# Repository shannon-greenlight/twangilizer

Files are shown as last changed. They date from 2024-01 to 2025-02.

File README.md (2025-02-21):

# Twangilizer - 4 Harmonic Tracking Oscillator with 4 VCAs
Twangilizer is a 20HP Eurorack module designed and made by Greenface Labs.
Used in conjunction with a VCO and a multiple-output CV generating module such as the Bonkulator, Twangilizer is a great way to set the amplitude envelopes of a tone and 4 of its harmonics. 
The harmonics are selectable from 1f, 2f, 3f, 4f, 5f, 6f, 7f and 8f. They are available as square waves at the output jacks 1-4.
The harmonics are also used to generate 10-step sine-wave approximations. The amplitudes of these waves are set by the CV inputs and then added to form the analog signal output.

Twangilizer features one signal input, an analog signal output, 4 digital harmonic outputs, 4 CV bias level adjustment pots, and four CV inputs to the VCAs.
It also features harmonic selection controls: Four 8 position rotary switches to select the harmonic from the above list. And there is a toggle switch per channel that selects divide by one, or divide by two.

The signal input level must be greater than .1Vp-p for the phase-locked loop circuits to be able to lock on.
The output signal ranges from 0 to 10Vp-p. The CV inputs range is 0 - 10V.

These repos contain the materials needed to construct the Twangilizer main board and the front panel. The files are for KiCAD 6.0. 
Go to the Greenlight Kicad repo to get the needed libraries. The gerber files work with JLCPC and will most likely work with other board manufacturers.

When using the JLCPCB assembly service, the BOM is split into 3 parts.
- bom/lcsc/main_bom.xlsx : The parts to be assembled by JLCPCB
- bom/digi-key/main_split.xlsx : The remaining parts to be assembled by user
- bom/other/other_bom.xlsx : The parts that must be bought from sources other than JLCPCB and Digi-Key

Also, when an assembly service is used, a component position file is required. This file's path is: fab/main_cpl.xlsx

notes: 	The cpl files are auto-generated from the .pos files produced by KiCAD. The bom files are generated by generate_boms.bat. You will need to refresh the data and save the file when changes to 
the schematic that affect the BOM or changes to the board layout occur. 
If they exist, the extra parts and additional data fields that appear on the schematic help to produce the different BOM files. 
They must be maintained for these BOMs to come out right.

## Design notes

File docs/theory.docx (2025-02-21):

# Twangilizer Theory of Operation

## Description:

The Twangilizer is a Eurorack module that fits in a 3U x 20HP format. It is an “additive synthesis” module that generates four sine waves that are harmonically related to a given input signal.

Using the 8-position rotary switches, the user can select from 8 harmonics (1f – 8f). The resulting signals can be used as-is or can be halved in frequency by the toggle switches. This gives the user many interesting options when creating a sound.

The levels of the resulting harmonics can be adjusted using the front panel potentiometers and/or via the CV inputs. An indicator LED displays the level of the adjustment.

## Inputs:

1. Clock input. Accepts signals > .1V peak-to-peak. 20 – 20KHz. An LED indicates CLK present.
2. CV1 – CV4. Control the level of the harmonics sent to Analog Out. 0-8V range.

## Outputs:

1. Analog Out. Sum of all four harmonics.
2. Sync Outputs 1-4. Digital outputs of the four harmonics. For syncing other modules.

## Several circuit blocks are used to implement the Twangilizer:

1. Power Supply
2. Clock capture
3. Harmonic generators
4. Waveform generators
5. Tracking Filters
6. Signal reconstruction
7. VCAs
8. Digital Outputs
9. Analog Output

## Power Supply

The power connector is “Either Way” but should be tested with a diode tester to make sure the diodes have been installed correctly. BAT54 SCHOTTKY diodes are used. They are rated at 200mA. The +12V rail pulls 100mA max and the -12V rail much less than that. Assuming a total current of 150mA through the package with a worst-case 1V drop, we get a power dissipation of only 150mW. According to the datasheet, derating occurs at 50C, so overheating under normal operating conditions shouldn’t be an issue.

The resulting voltages after the diode drops are typically +11.5V and -11.6V given +/-12V inputs. This leaves enough headroom for the op amps that may need to deal with +/-10V signals.

The +9V rail is derived from the +12V supply. The -9V rail is derived from +9V.

The harmonic and waveform generators use +9V and -9V. These functions require good regulation to achieve a stable waveform. The LM317 used for the +9V requires a certain amount of headroom (see further discussion at end of this document), or else +10V would have been chosen, as the PLLs work best with higher supply voltages. However, 9V is good enough. The -9V rail requires less than 200uA, so an op amp regulator is ideal here.

The symmetry of the waveform depends on the absolute value of the -9V rail being close to the +9V rail. For this reason, .1% resistors were chosen.

Also, the bias point for the VCO pickoff circuits is set by the -9V. This is a sensitive parameter, so it needs to be accurate. A 500ohm trimpot adjusts the +9V rail. With components at their nominal values, an adjustment range of 8.61V – 9.62V is achieved. The nominal adjustment range is skewed so that the worst-case range is adequate and as symmetrical about the 9V value as possible. The results of this are:

1. Set RV1 to 200ohms for 9.01V when all components are nominal.
2. Worst case lower value is 8.76V
3. Worst case upper value is 9.21V

Refer to lm317.xlsx for the calculations used in this discussion.

### Tests

1. D1 – D4 correctly installed
2. +12 > 11.4
3. -12 > -11.5
4. Adjust +9V between 8.95V and 9.05V
5. -9V within .5% of +9V magnitude.

## Clock Capture

The clock capture circuit supplies the signal to the harmonic generators. It is spec'd for a signal greater than .1Vpp in amplitude and works in the range of 20Hz – 20KHz.

Refer to spice\CLK Pickoff.asc for the following discussion.

The input signal is AC coupled and then low-pass filtered. The signal is then given a gain of 46.2 which forms a band pass filter whose characteristics are shown in the graph below.

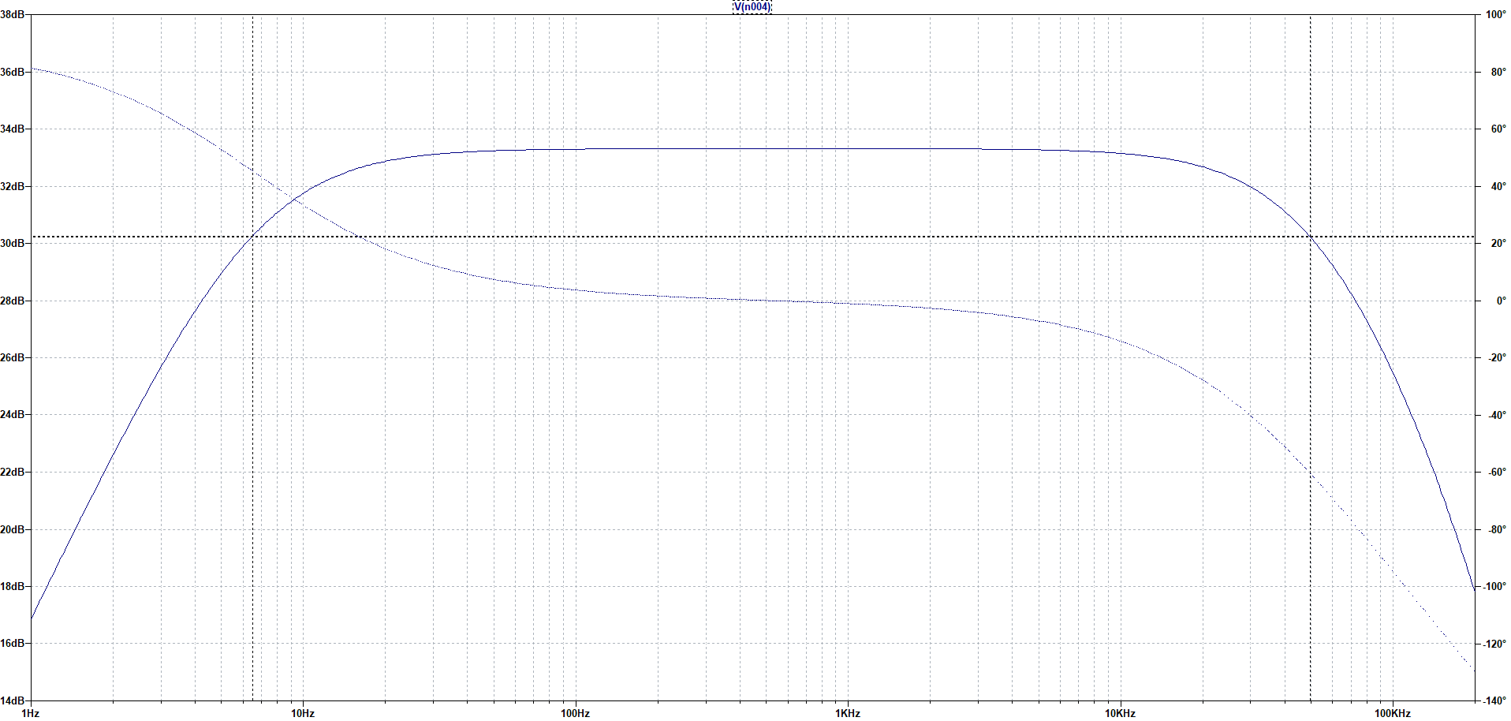
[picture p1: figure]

The -3dB points are approximately 6.6Hz and 50KHz.

This signal is passed to a comparator which has a hysteresis of .94V. The comparator’s trip point is skewed slightly positive from 0V. This prevents the Clock Present LED from lighting when no signal is present due to offset voltage errors inherent in the op amp.

Finally, the signal is sent to a transistor circuit that level-shifts it to a 9V digital wave that is compatible with the harmonic and waveform generators.

Another transistor circuit drives a “Clock Present” indicator LED.

All tests are performed with a 30mVpp sine wave input.

### Tests

1. CLK waveform good at 20Hz
2. CLK waveform good at 20KHz
3. No CLK at 10Hz
4. No CLK at 30KHz
5. CLK present indicator OFF when no clock is present
6. CLK present indicator ON when clock is present

## Harmonic Generators

The harmonics are generated using phase locked loops with down counters whose outputs are routed to the reset input via the 8-position rotary switches. This arrangement creates a frequency multiplier of 1f – 8f depending on the position of the switch. The signal can be further modified by the toggle switches that follow. These are either connected to the signal or to a flip-flop that divides the frequency in half. When the frequency divider position is chosen, you get the resulting frequencies: 1/2f, 1f, 3/2f, 2f, 5/2f, 3f, 7/2f, 4f.

There is a foible in the circuit when in 1f mode. A race condition exists that sometimes results in the output signal oscillating at around 110KHz. This is fixed by the slight delay added to the 1f position via a 1K resistor and 10pF capacitor.

No testing is needed here unless subsequent stages fail.

If testing is required, the signal can be measured at the center pin of the divide-by-two toggle switches. A 1KHz clock signal is adequate for the following tests.

### Tests

1. CLK signal correct for all 8 rotary switch settings
2. CLK signal correct for both toggle switch settings

## Waveform Generators

The outputs of the Harmonic Generators are fed to the Waveform Generators which create the sinewave approximations. These 10-step waveforms are created by CD4046/CD4017 combinations that are similar to the Harmonic Generators.

But instead of selectable ratios, these circuits are set to multiply by 10. Each output of the CD4017 is sent through a resistor to a summing amplifier. The gain of this amp is set to produce a signal compatible with the next stage. The resulting signal from the Waveform Generators is -3dBm @600 or .547VRMS.

The peak value of the current going into the summing junction is set at 15uA. So, the current will vary from -15uA to +15uA to create a bipolar signal at the output. But, since only positive currents are available from the +9V powered CD4017, a -45uA offset is added using -9V through a 200K resistor. This offset must be accounted for in the resistor calculation.

In the equation below, we see 15uA as the peak current times the sine of the sum of 0-.9 and a phase offset of .125 (to improve wave shape) times 2π. The 45uA offset is added to this value.

Note that the sine calculation is in Radians.

Refer to wavegen.xlsx for the following discussion.

Here is the Excel calculation for the ideal resistor values: (see below table)

G =0.000015*SIN((F?+.125)*6.2832)+0.000045 defines current through the resistor

H =9/G? defines ideal resistor value

F | G | H
0 | 5.56066E-05 | 161851.2
0.1 | 5.98153E-05 | 150463.1
0.2 | 5.83651E-05 | 154201.8
0.3 | 5.18098E-05 | 173712.4
0.4 | 4.26534E-05 | 211003.3
0.5 | 3.43933E-05 | 261678.9
0.6 | 3.01846E-05 | 298164.8
0.7 | 3.1635E-05 | 284495.2
0.8 | 3.81903E-05 | 235661.8
0.9 | 4.73467E-05 | 190087

Real resistor values have been substituted in the following table and graph:

I | J | K
162000 | 1.06E-05 | -0.55206
1.50E+05 | 0.000015 | -0.7845
1.54E+05 | 1.34E-05 | -0.70299
1.74E+05 | 6.72E-06 | -0.35167
2.10E+05 | -2.1E-06 | 0.112071
2.61E+05 | -1.1E-05 | 0.550052
3.00E+05 | -1.5E-05 | 0.7845
2.87E+05 | -1.4E-05 | 0.71343
2.37E+05 | -7E-06 | 0.367424
1.91E+05 | 2.12E-06 | -0.1109
162000 | 1.06E-05 | -0.55206
1.50E+05 | 0.000015 | -0.7845
1.54E+05 | 1.34E-05 | -0.70299
1.74E+05 | 6.72E-06 | -0.35167
2.10E+05 | -2.1E-06 | 0.112071
2.61E+05 | -1.1E-05 | 0.550052
3.00E+05 | -1.5E-05 | 0.7845
2.87E+05 | -1.4E-05 | 0.71343
2.37E+05 | -7E-06 | 0.367424
1.91E+05 | 2.12E-06 | -0.1109

J =9/I?-0.000045

K =-52300*J?

Equation K shows the 52.3K resistor that sets the gain of the summing amplifier.

Dividing the peak value of .7845V by the square root of two results in .555VRMS. The 100pF cap in the feedback filters the high frequency components (-3dB @30KHz) of the signal and reduces the amplitude to near the desired .547VRMS.

The Tracking Filters in the next section take their input from the VCO pins of the CD4046s. The response of the PLLs must be adjusted to work with the Tracking Filters. Set the input clock frequency to 1KHz and adjust the pot (RV6-RV9) until a voltage of -4.2V is measured at the VCO pickoff test points. (TP8 – TP11).

### Tests (measured at TP4 – TP7)

1. OSC waveform good at 20Hz
2. OSC waveform good at 20KHz

## Tracking Filters

The job of the tracking filters is to produce sine waves from the approximate waveforms formed by the Waveform Generators described above. The tracking filters use the VCO in of the PLL chips to sense the frequency and set the corner frequency of the filters as required.

The CD4046 phase locked loop IC has a capture range defined by the RC combination of the cap that appears between pins 6 and 7 and the resistor chain that is connected to pin 11. With a resistor that has a nominal value of 35K (10K plus half the 50K of the trimpot) and a capacitor of 2.2nF, you get a center frequency around 20KHz when the circuit is configured as a 10f multiplier. See fig. 5 in the data sheet.

Increasing RC reduces the upper capture point and increases the slope of the pickoff curve.

The graph below shows the pickoff level vs. the input clock frequency.

The filters use a signal that ranges from -10VDC to +10VDC to set their cutoff frequency. The table below shows the Ideal curve which was empirically derived. It also shows the results measured from a v0.0 Twangilizer VCO Pickoff. Finally, it shows the computed curve.

Refer to VCO Pickoff Meas.xlsx for the following data.

Freq | Ideal | VCO Pickoff | Computed
5000 | 10.2 | 7.68 | 17.64
4000 | 10 | 6.18 | 11.265
3000 | 5 | 4.77 | 5.2725
2000 | 0 | 3.47 | -0.2525
1000 | -5 | 2.27 | -5.3525
500 | -7.62 | 1.71 | -7.7325
250 | -9.06 | 1.43 | -8.9225
100 | -9.88 | 1.25 | -9.6875
50 | -10.17 | 1.16 | -10.07
20 | -10.17 | 1.07 | -10.4525

Planned =(Pickoff*4.25)-15 The resulting curve for the tracking filters looks something like the following measured trace:

The signal from the VCO is not a pure DC signal. It contains pulses that continually correct the output frequency. These pulses must be filtered lest they affect the output signal. A single stage filter with a cutoff frequency of 6.8KHz accomplishes this task. The 499K pickoff resistor and a 47pF cap is used.

A spreadsheet that was used to select resistor values is found here: VCO Pickoff Plan.xlsx

### Tests

Measure at TP12 – TP19

1. 1f waveform good at 20Hz CLK
2. 1f waveform good at 5KHz CLK
3. Measure 50Hz at 100Hz CLK for 1f/2
4. 2f waveform good at 20Hz CLK
5. 2f waveform good at 5KHz CLK
6. 3f waveform good at 20Hz CLK
7. 3f waveform good at 6.67KHz CLK
8. 4f waveform good at 5KHz CLK
9. 5f waveform good at 20Hz CLK
10. 5f waveform good at 4KHz CLK
11. 6f waveform good at 20Hz CLK
12. 6f waveform good at 3.33KHz CLK
13. 7f waveform good at 20Hz CLK
14. 7f waveform good at 2.86KHz CLK
15. 8f waveform good at 20Hz CLK
16. 8f waveform good at 2.5KHz CLK

## VCAs

Now that the frequency of the harmonic has been set and the tracking filter has turned the output of the waveform generator into a sine wave, the level must be set. This is accomplished using a voltage-controlled amplifier.

See spice\VCA.asc

There are two control inputs to the VCA, one from the CV input jack which is protected in the usual way with a 510ohm resistor and a BAT54S; and one set by the CV bias potentiometer. The 510ohms is small enough in resistance to be insignificant to the 120K input.

Since the bias pot uses +9V as its reference, the voltage divider is adjusted to match the range of the CV input by the 150K resistor. In either case, this sets the full-scale voltage value at the non-inverting input of the op amp to be 5V. This implies 5V at the inverting input which sets an LED current of 250uA. (5V / 20K)

When the CV bias pot is used in conjunction with the CV input, the bias sets a current level that is increased by the CV input only when it exceeds the voltage level of the CV bias. A transfer function curve of CV input vs LED current best illustrates this. The bias pot is set to 50% in this example.

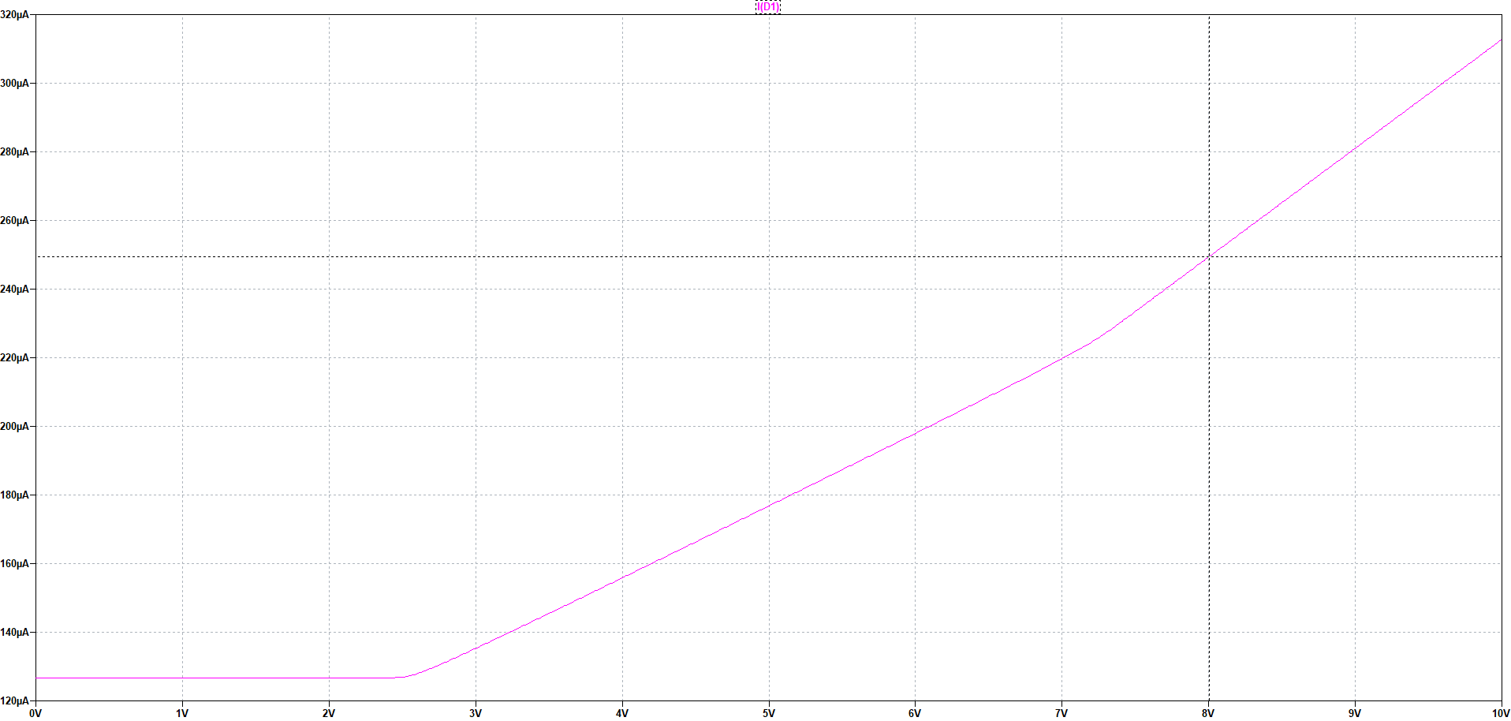
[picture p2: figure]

Here we see the LED current at 125uA until the CV input is greater than 2.5V. This is because diode D4 does not conduct until the CV input exceeds 2.5V. The current then increases with CV until the maximum of 250uA is reached.

With the CV bias set to 100%, the base current will be 250uA. In this case the CV input will increase the current to a maximum of 330uA with the increase starting when the CV input exceeds 5V.

In the above example, the slight upturn when CV input is greater than 7V occurs when D3 becomes reverse biased.

BAT54 Schottky diodes are placed in series with the sense resistors to minimize interaction due to resistive loading. According to the manual, the maximum leakage current of a BAT54 at 25V is 2uA. The worst-case condition in this circuit is 10V. The manual indicates the typical leakage at 10V is .1uA. The manual also states that, for the current this circuit will experience, the diodes will have a forward voltage drop of only .12V. Conveniently, these are the values that are used by the Spice simulator.

The VCA circuit uses a vactrol as the controlled element. The NSL-32SR3 has a nominal resistance of 600 ohms with an LED current of 250uA. The output of the Signal Reconstruction element is approximately 3.5Vp-p. This must be raised to the specified output level of 10Vp-p. This implies a gain of 2.86 which is realized by the 1K in series with the 2K trimpot at 50% divided by the 600 ohms of the full-scale resistance of the vactrol.

This also gives a transfer function of roughly 1V at CVin equals 1Vpp at Analog Out.

An indicator LED is put in series with the vactrol LED as an indication of the control voltage level.

### Tests

Measure at Analog Output, CLK input 1000Hz.

1. 0V CV, bias adjustment off. Measure < .1VRMS.
2. 1V CV, bias adjustment off. Measure 1Vpp +/-2%
3. 8V CV, bias adjustment off. Measure 8Vpp +/-2%
4. 0V CV, bias adjustment 50%. Measure 5Vpp +/-5%
5. 0V CV, bias adjustment 100%. Measure 10Vpp +/-5%

## Digital Outputs

The digital outputs are +5V square waves generated from the outputs of the Harmonic Generators. These outputs are 9V square waves and must be level-shifted to the required 5V. The 9V signal is reduced to 4.9V by a resistive divider formed by 10K and 12K resistors. This is fed into the non-inverting input of an op amp.

A 20pF capacitor from the non-inverting input to ground limits the slew rate of the input signal which minimizes ringing at the output.

The output is protected by the usual 510 ohm/BAT54S combination.

## Analog Output

The analog output is the sum of the four VCA outputs. It is followed by a 4th order Butterworth 5KHz low pass filter. The output is protected by the usual 510ohm/BAT54 circuit.

The curve of the filter is modeled in the file: spice\final_output.asc

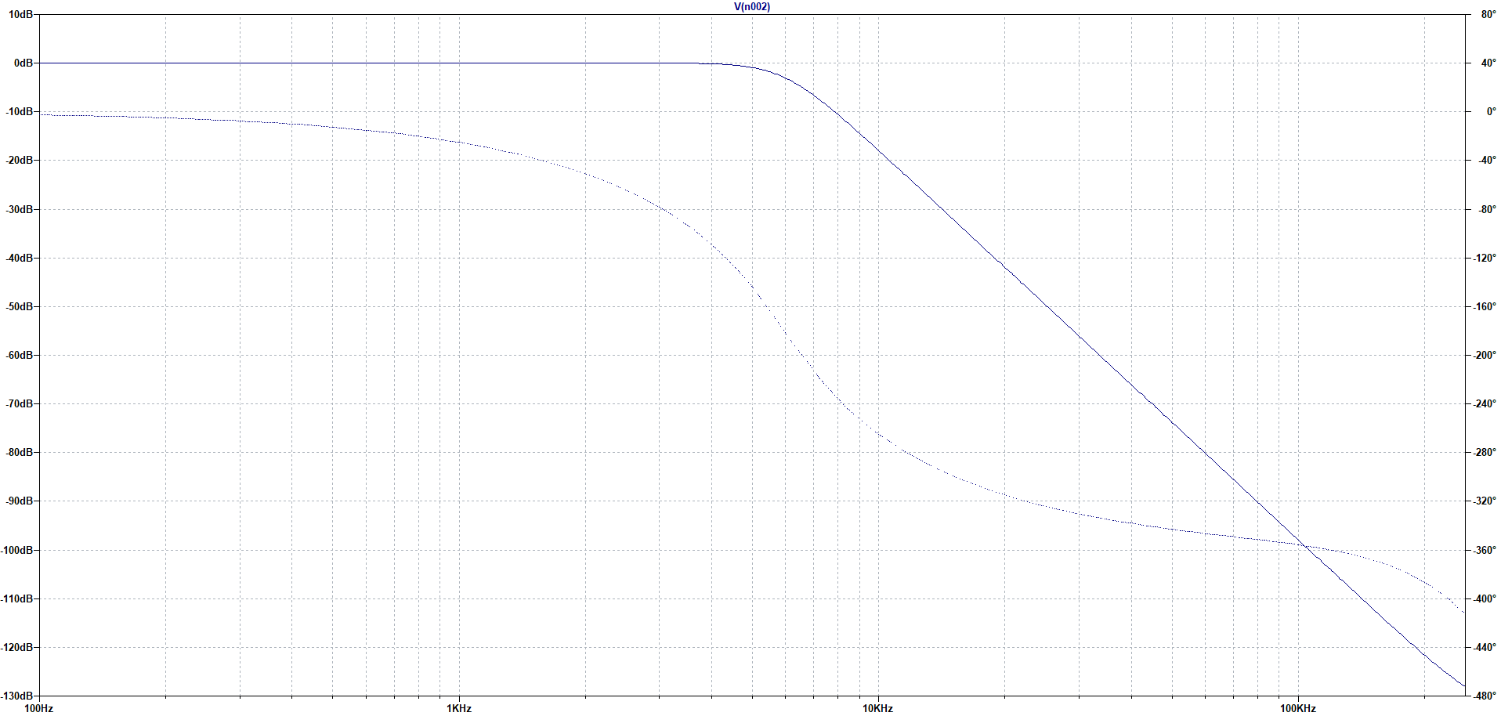
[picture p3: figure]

## Clip Detector

The clip detector circuit is placed at the analog output of the Twangilizer and is set to detect clipping when the signal exceeds 9Vpk. The circuit is unique for a clip detector in that it flashes an LED at a rate proportional to the amount of clipping. This is opposed to increasing the intensity of the LED as the signal level increases.

This behavior is desirable because a flashing LED is more noticeable than a steady-state LED of varying brightness.

The circuit consists of a non-precision full-wave rectifier followed by a comparator .

The circuit is pictured below. The SPICE simulation is below that.

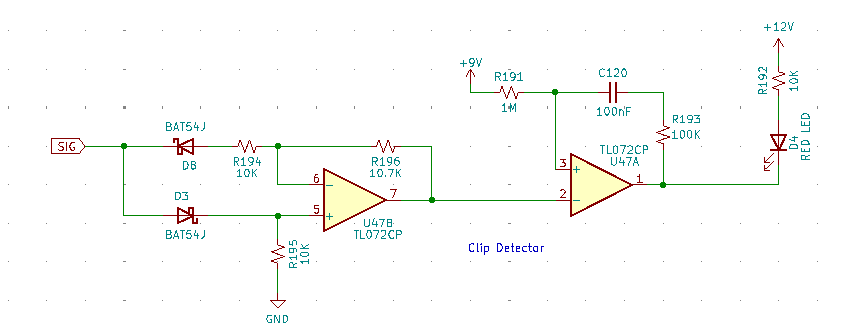
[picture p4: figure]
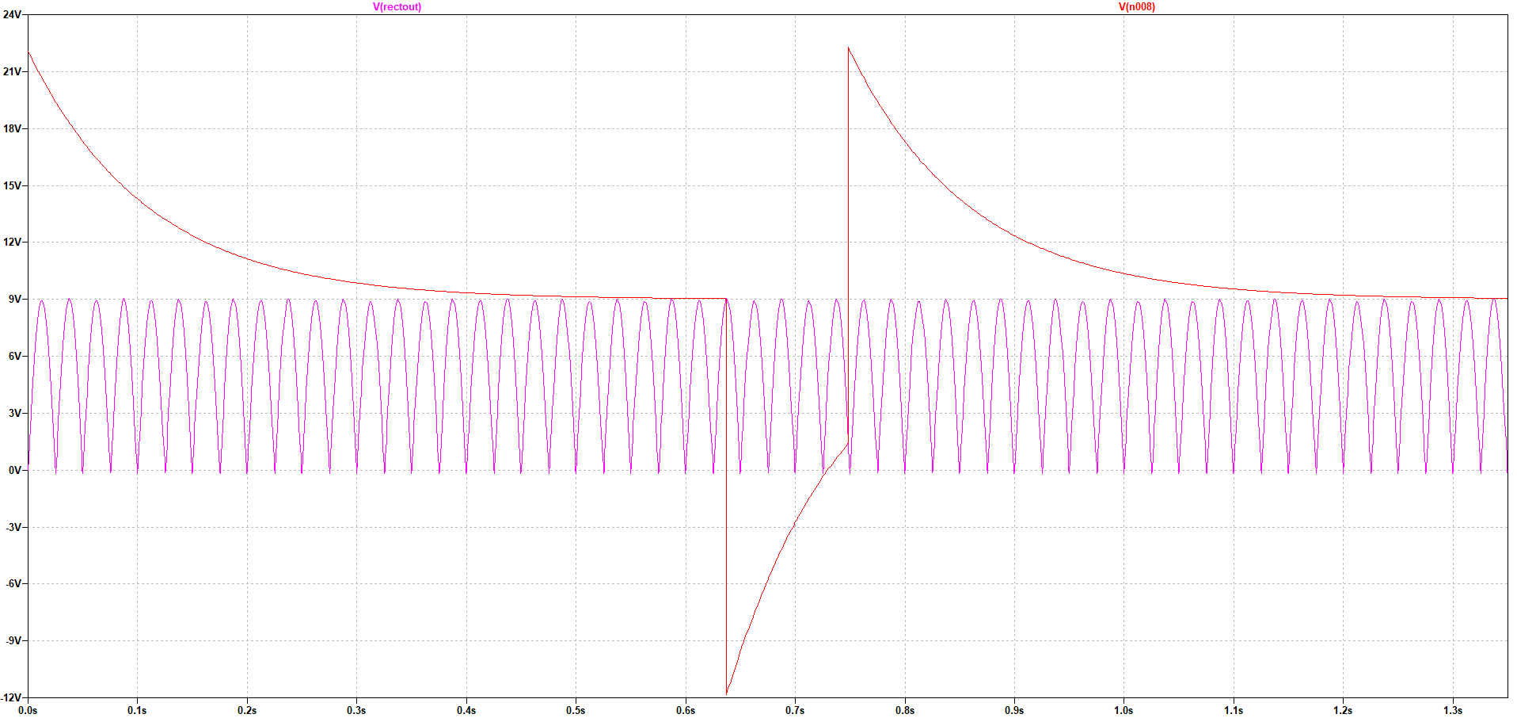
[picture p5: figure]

The two traces are:

1. The rectified sine wave is the input signal. 20Hz at 9.7Vpk. This is at the -input of the comparator.
2. The red wave is the +input of the comparator.

The output of the comparator is not shown, but closely follows the red trace. It charges the capacitor to levels above and below that of the input signal as it switches. This “bump” in voltage creates the delay that makes the circuit oscillate when the input exceeds +9Vpk.

Note that when pin2 (the -input) goes more positive than the voltage at pin 3 (the +input), the output of the comparator will switch to the negative state. And when the voltage at pin 2 is more negative than the voltage at pin 3, the output will switch positive.

So, when the input signal is small, the capacitor will take longer to discharge to the level of the signal, resulting in a slower oscillation. When the input signal is large, the capacitor will discharge to the level of the signal sooner, resulting in faster oscillation.

The 100K resistor is there to damp the current in the capacitor to prevent the input voltage from going below the negative rail. See the LM393 data sheet for more information about allowable voltage levels.

## Further Discussion

1. The LM317 manual states that 3V of headroom is recommended to maintain maximum current without overheating. However, the 9V circuitry of the Twangilizer draws very little current. The manual also states that the part requires greater than 1.25V headroom. Giving the part 1.5V of headroom at minimum means that the +12V rail (after the reverse protection diode) must be at least 10.5V. This translates to an input of 11V or greater, which is easily realizable in Eurorack systems.

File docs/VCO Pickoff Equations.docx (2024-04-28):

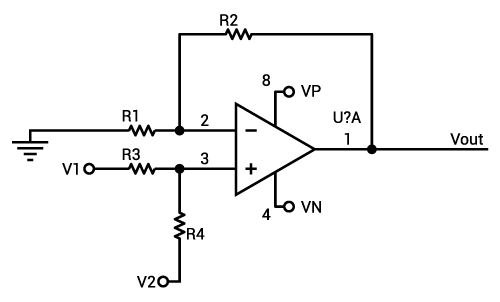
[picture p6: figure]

Vout = 4.5V1 – 14.5

V2 = -9V

A = (R2/R1 + 1)

Iin = (V2 – V1) / (R3 + R4)

Iin = -9 / (R3 + R4) when V1 = 0

R3 + R4 = 4e6

Iin = -9/4e6 = -2.25e-6

V+ = (V2 – V1) + R4Iin = -9 + R4(-2.25e-6)

V+ = -9 + -9R4/(R3 + R4)

V+ = -9(1 + R4/(R3 + R4))

V+/-9 = 1 + R4/(R3 + R4)

V+/-9 - 1 = R4/(R3 + R4)

V+ = (V2 – V1)(1 + R4/(R3 + R4))

V+/(V2 – V1) = 1 + R4/(R3 + R4)

V+/(V2 – V1) - 1 = R4/(R3 + R4)

A(V2 R3 / R3 + R4) = -14.5 when V1 = 0

AR4/(R3 + R4) = 4.5

AR4 = 4.5(R3 + R4)

AR4 – 4.5R4 = 4.5R3

R3 = (AR4 – 4.5R4)/4.5

R3 = R4(A – 4.5) / 4.5

-9R3 / -14.5 = R3 + R4

.6207R3 – R3

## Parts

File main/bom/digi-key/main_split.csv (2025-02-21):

Reference | Quantity | Value | Digi-Key Part #
D4, | 1 | RED LED | 732-5005-ND
D16, | 1 | GREEN LED | 732-5007-ND
D25, D26, D27, D28, | 4 | YELLOW LED | 732-5010-ND
J1, J2, J3, J4, J5, J7, J8, J9, J10, J11, | 10 | 3.5mm Jack | WM17366-ND
J12, | 1 | Eurorack Power Cable | H3CCS-1618G-ND
KN1, KN2, KN3, KN4, | 4 | Mult Knob | 1722-1314-ND
KN5, KN6, KN7, KN8, | 4 | CV Knob | 4654-FC7251-ND
RV10, RV11, RV14, RV15, | 4 | 1K | PTV09A-4020F-B102-ND
SC2, SC4, SC6, SC8, | 4 | Mounting Screw | 335-1156-ND
SO1, SO2, SO3, SO4, SO5, | 5 | LED Spacer 9mm | RPC4262-ND
SW1, SW2, SW3, SW8, | 4 | SW_Rotary8 | 1528-2925-ND
SW4, SW5, SW6, SW7, | 4 | SW_SPDT | 2449-ANT11SF1CQE-ND
U30, U31, U34, U35, | 4 | NSL-32SR3 | NSL-32SR3-ND

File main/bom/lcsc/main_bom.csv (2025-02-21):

Designator | Comment | Footprint | JLCPCBPart#
C1, C2, | 100uF | Capacitor_SMD:CP_Elec_6.3x5.4_Nichicon | C2887272
C3, C6, C46, C47, | 20pF | Capacitor_SMD:C_0603_1608Metric_Pad1.08x0.95mm_HandSolder | C1648
C4, C5, C10, C15, C16, C18, C19, C29, C31, C32, C33, C34, C35, C36, C37, C38, C39, C54, C55, C58, C59, C60, C61, C62, C63, C66, C67, C68, C69, C80, C81, C82, C83, C84, C85, C86, C87, C94, C95, C96, C97, C98, C99, C100, C101, C102, C103, C104, C105, C106, C107, C108, C109, | 100nF | Capacitor_SMD:C_0805_2012Metric_Pad1.18x1.45mm_HandSolder | C49678
C7, | 220nF | Capacitor_SMD:C_0805_2012Metric_Pad1.18x1.45mm_HandSolder | C5378
C8, C22, C23, C24, C28, | 330pF | Capacitor_SMD:C_0603_1608Metric_Pad1.08x0.95mm_HandSolder | C1664
C9, C44, C45, C48, C49, C77, C114, C115, C116, C117, C118, C119, C120, C121, C122, | 100nF | Capacitor_SMD:C_0603_1608Metric | C14663
C11, C25, C26, C27, C30, | 10uF | Capacitor_SMD:C_0805_2012Metric_Pad1.18x1.45mm_HandSolder | C15850
C12, C17, | 2.7nF | Capacitor_SMD:C_0805_2012Metric_Pad1.18x1.45mm_HandSolder | C97900
C13, | 2nF | Capacitor_SMD:C_0603_1608Metric_Pad1.08x0.95mm_HandSolder | C2168932
C14, C40, C43, C50, C51, | 2.2uF | Capacitor_SMD:C_0603_1608Metric_Pad1.08x0.95mm_HandSolder | C23630
C20, | 270pF | Capacitor_SMD:C_0805_2012Metric_Pad1.18x1.45mm_HandSolder | C527216
C21, C76, C78, C79, | 10pF | Capacitor_SMD:C_0603_1608Metric_Pad1.08x0.95mm_HandSolder | C1634
C41, C42, C88, C89, C90, C91, C92, C93, | 22nF | Capacitor_SMD:C_0805_2012Metric_Pad1.18x1.45mm_HandSolder | C77069
C52, C53, C70, C71, | 2.2nF | Capacitor_SMD:C_0603_1608Metric_Pad1.08x0.95mm_HandSolder | C1604
C56, C57, C72, C73, | 4.7uF | Capacitor_SMD:C_0805_2012Metric_Pad1.18x1.45mm_HandSolder | C1779
C64, C65, C74, C75, | 100pF | Capacitor_SMD:C_0603_1608Metric_Pad1.08x0.95mm_HandSolder | C14858
C110, C111, C112, C113, | 22nF | Capacitor_SMD:C_0603_1608Metric_Pad1.08x0.95mm_HandSolder | C21122
D1, D2, D5, D6, D7, D9, D13, D17, D18, D19, D20, D21, | BAT54S | Package_TO_SOT_SMD:SOT-23 | C916425
D3, D8, D31, D32, D33, D34, D35, D36, D37, D38, | BAT54J | Diode_SMD:D_SOD-323F | C12744
D15, | 1N4148 | Diode_SMD:D_SOD-123 | C81598
J6, | 2x5 Header | Connector_PinHeader_2.54mm:PinHeader_2x05_P2.54mm_Vertical_SMD | C19268827
J13, | Conn_01x02_Male | Connector_PinHeader_2.54mm:PinHeader_1x02_P2.54mm_Vertical | C2905434
Q2, | MMBT3904 | Package_TO_SOT_SMD:SOT-23 | C20526
Q3, | MMBT3906 | Package_TO_SOT_SMD:SOT-23 | C266589
R1, R2, R3, R4, R28, R44, R45, R48, R49, | 510 | Resistor_SMD:R_0805_2012Metric_Pad1.20x1.40mm_HandSolder | C2842425
R5, R6, R7, R8, R9, R14, R30, R31, R32, R39, R42, R43, R50, R51, R80, R81, R130, R133, R141, R143, R145, R150, R151, R152, R192, R194, R195, R216, R217, | 10K | Resistor_SMD:R_0603_1608Metric | C25804
R10, R15, | 10K .1% | Resistor_SMD:R_0603_1608Metric | C95204
R11, R16, | 100K | Resistor_SMD:R_0805_2012Metric_Pad1.20x1.40mm_HandSolder | C149504
R12, R25, | 2K | Resistor_SMD:R_0603_1608Metric | C22975
R13, | 88.7K | Resistor_SMD:R_0603_1608Metric | C163418
R17, | 7.87K | Resistor_SMD:R_0603_1608Metric | C103822
R18, | 3.65K | Resistor_SMD:R_0603_1608Metric_Pad0.98x0.95mm_HandSolder | C137730
R19, | 5.1K | Resistor_SMD:R_0603_1608Metric | C23186
R20, R23, | 16.5K | Resistor_SMD:R_0603_1608Metric | C227613
R21, | 620 | Resistor_SMD:R_0805_2012Metric_Pad1.20x1.40mm_HandSolder | C144551
R22, | 200K | Resistor_SMD:R_0805_2012Metric_Pad1.20x1.40mm_HandSolder | C17539
R24, R27, | 68K | Resistor_SMD:R_0805_2012Metric_Pad1.20x1.40mm_HandSolder | C17801
R26, | 59K | Resistor_SMD:R_0603_1608Metric | C218088
R29, R118, R119, R128, R129, R131, R132, R138, R139, R142, R144, R146, R147, R148, R149, R165, R166, R167, R168, R169, R170, R211, R212, R213, R214, | 1K | Resistor_SMD:R_0603_1608Metric | C21190
R33, R35, R37, R40, R52, R54, R82, R84, | 27K | Resistor_SMD:R_0805_2012Metric_Pad1.20x1.40mm_HandSolder | C17593
R34, R36, R38, R41, R53, R55, R83, R85, | 1.5K | Resistor_SMD:R_0805_2012Metric_Pad1.20x1.40mm_HandSolder | C4310
R46, R47, R218, R219, | 12K | Resistor_SMD:R_0603_1608Metric | C22790
R56, R62, R86, R91, | 162K | Resistor_SMD:R_0603_1608Metric | C217756
R57, R63, R87, R92, | 154K | Resistor_SMD:R_0603_1608Metric | C321731
R58, R64, R88, R93, R112, R115, R122, R125, | 210K | Resistor_SMD:R_0603_1608Metric | C227705
R59, R65, R89, R94, | 300K | Resistor_SMD:R_0603_1608Metric | C23024
R60, R61, R90, R95, | 237K | Resistor_SMD:R_0603_1608Metric | C403089
R66, R73, R96, R102, R114, R117, R124, R127, | 150K | Resistor_SMD:R_0603_1608Metric | C22807
R67, R74, R97, R103, | 174K | Resistor_SMD:R_0603_1608Metric | C2933159
R68, R75, R98, R104, | 261K | Resistor_SMD:R_0603_1608Metric | C2930083
R69, R76, R99, R105, | 287K | Resistor_SMD:R_0603_1608Metric | C5159700
R70, R72, R100, R106, | 191K | Resistor_SMD:R_0603_1608Metric | C321771
R71, R77, R101, R107, | 200K | Resistor_SMD:R_0603_1608Metric | C25811
R78, R79, R108, R109, | 52.3K | Resistor_SMD:R_0603_1608Metric | C23198
R110, R111, R120, R121, | 120K | Resistor_SMD:R_0603_1608Metric | C25808
R113, R116, R123, R126, R134, R135, R137, R153, R154, R155, R156, R157, R158, R162, R163, R164, | 20K | Resistor_SMD:R_0603_1608Metric | C4184
R136, R140, R159, R160, R161, R171, R172, R173, R215, | 4.7K | Resistor_SMD:R_0603_1608Metric | C23162
R174, R175, R176, R177, R186, R187, R188, R189, R191, | 1M | Resistor_SMD:R_0603_1608Metric | C22935
R178, R179, R180, R181, | 205K | Resistor_SMD:R_0603_1608Metric | C22949
R182, R183, R184, R185, | 2.55M | Resistor_SMD:R_0603_1608Metric | C422950
R190, R193, | 100K | Resistor_SMD:R_0603_1608Metric | C25803
R196, | 10.7K | Resistor_SMD:R_0603_1608Metric | C22857
RV1, | 500 | Potentiometer_SMD:Potentiometer_Bourns_3224W_Vertical | C116324
RV2, RV3, RV4, RV5, RV6, RV7, RV8, RV9, | 50K | sputterizer:HDK_3mm | C913246
RV12, RV13, RV16, RV17, | 5K | Potentiometer_SMD:Potentiometer_Bourns_3224W_Vertical | C81349
TP1, TP2, TP3, TP4, TP5, TP6, TP7, TP12, TP20, TP21, TP23, TP24, | TestPoint | TestPoint:TestPoint_Loop_D2.54mm_Drill1.5mm_Beaded | C5199801
U1, U3, U5, U16, U17, U22, U23, U28, U29, U32, U33, U47, | TL072CP | Package_SO:SOIC-8_3.9x4.9mm_P1.27mm | C6961
U2, U36, U38, U39, U40, U44, U45, U46, | TL071 | Package_TO_SOT_SMD:SOT-353_SC-70-5 | C4370475
U4, | LM317_SOT-223 | Package_TO_SOT_SMD:SOT-223-3_TabPin2 | C347367
U6, U7, U8, U14, U18, U19, U24, U25, | CD4046 | Package_SO:TSSOP-16_4.4x5mm_P0.65mm | C2651240
U9, U10, U11, U15, U20, U21, U26, U27, | CD4017 | Package_SO:SOIC-16_3.9x9.9mm_P1.27mm | C356694
U12, U13, | CD4013 | Package_SO:SOIC-14_3.9x8.7mm_P1.27mm | C13527
U37, U41, U42, U43, | LM13700 | Package_SO:SOIC-16_3.9x9.9mm_P1.27mm | C174050

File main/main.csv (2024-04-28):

Reference | Quantity | Value | Footprint | Datasheet | Digi-Key Part | LCSC Part #
C1 C2 | 2 | 100uF | Capacitor_SMD:CP_Elec_6.3x5.4_Nichicon | http://www.rubycon.co.jp/en/catalog/e_pdfs/aluminum/e_ml.pdf | 399-EDH107M016A9GAACT-ND | C2887272
C11 C25 C26 C27 C30 | 5 | 10uF | Capacitor_SMD:C_0805_2012Metric_Pad1.18x1.45mm_HandSolder | http://datasheets.avx.com/SR-Series.pdf | 399-9886-1-ND | C15850
C110 C111 C112 C113 | 4 | 22nF | Capacitor_SMD:C_0603_1608Metric_Pad1.08x0.95mm_HandSolder | http://datasheets.avx.com/SR-Series.pdf | 478-10836-1-ND | C21122
C12 C17 | 2 | 2.7nF | Capacitor_SMD:C_0805_2012Metric_Pad1.18x1.45mm_HandSolder | http://datasheets.avx.com/SR-Series.pdf | 399-9877-1-ND | C97900
C13 | 1 | 2nF | Capacitor_SMD:C_0603_1608Metric_Pad1.08x0.95mm_HandSolder | http://datasheets.avx.com/SR-Series.pdf | 399-9877-1-ND | C2168932
C14 C40 C43 C50 C51 | 5 | 2.2uF | Capacitor_SMD:C_0603_1608Metric_Pad1.08x0.95mm_HandSolder | http://datasheets.avx.com/SR-Series.pdf | 399-9877-1-ND | C23630
C20 | 1 | 270pF | Capacitor_SMD:C_0805_2012Metric_Pad1.18x1.45mm_HandSolder | http://datasheets.avx.com/SR-Series.pdf | 399-9877-1-ND | C527216
C21 C76 C78 C79 | 4 | 10pF | Capacitor_SMD:C_0603_1608Metric_Pad1.08x0.95mm_HandSolder | http://datasheets.avx.com/SR-Series.pdf | BC2662CT-ND | C1634
C3 C6 C46 C47 | 4 | 20pF | Capacitor_SMD:C_0603_1608Metric_Pad1.08x0.95mm_HandSolder | http://datasheets.avx.com/SR-Series.pdf | BC2662CT-ND | C1648
C4 C5 C10 C15 C16 C18 C19 C29 C31 C32 C33 C34 C35 C36 C37 C38 C39 C54 C55 C58 C59 C60 C61 C62 C63 C66 C67 C68 C69 C80 C81 C82 C83 C84 C85 C86 C87 C94 C95 C96 C97 C98 C99 C100 C101 C102 C103 C104 C105 C106 C107 C108 C109 | 53 | 100nF | Capacitor_SMD:C_0805_2012Metric_Pad1.18x1.45mm_HandSolder | http://datasheets.avx.com/SR-Series.pdf | 478-10836-1-ND | C49678
C41 C42 C88 C89 C90 C91 C92 C93 | 8 | 22nF | Capacitor_SMD:C_0805_2012Metric_Pad1.18x1.45mm_HandSolder | http://datasheets.avx.com/SR-Series.pdf | BC2662CT-ND | C77069
C9 C44 C45 C48 C49 C77 C114 C115 C116 C117 C118 C119 | 12 | 100nF | Capacitor_SMD:C_0603_1608Metric | http://datasheets.avx.com/SR-Series.pdf | 478-10836-1-ND | C14663
C52 C53 C70 C71 | 4 | 2.2fF | Capacitor_SMD:C_0603_1608Metric_Pad1.08x0.95mm_HandSolder | http://datasheets.avx.com/SR-Series.pdf | BC2662CT-ND | C1604
C56 C57 C72 C73 | 4 | 4.7uF | Capacitor_SMD:C_0805_2012Metric_Pad1.18x1.45mm_HandSolder | http://datasheets.avx.com/SR-Series.pdf | 478-10836-1-ND | C1779
C64 C65 C74 C75 | 4 | 100pF | Capacitor_SMD:C_0603_1608Metric_Pad1.08x0.95mm_HandSolder | http://datasheets.avx.com/SR-Series.pdf | BC2662CT-ND | C14858
C7 | 1 | 220nF | Capacitor_SMD:C_0805_2012Metric_Pad1.18x1.45mm_HandSolder | http://datasheets.avx.com/SR-Series.pdf | 478-10836-1-ND | C5378
C8 C22 C23 C24 C28 | 5 | 330pF | Capacitor_SMD:C_0603_1608Metric_Pad1.08x0.95mm_HandSolder | http://datasheets.avx.com/SR-Series.pdf | 399-9877-1-ND | C1664
D1 D2 D5 D6 D7 D9 D13 D17 D18 D19 D20 D21 | 12 | BAT54S | Package_TO_SOT_SMD:SOT-23 | https://www.diodes.com/assets/Datasheets/ds11005.pdf | 4786-BAT54SCT-ND | C916425
D15 | 1 | 1N4148 | Diode_SMD:D_SOD-123 | http://www.vishay.com/docs/81857/1n4148.pdf | 1N4148VSCT-ND | C81598
D16 | 1 | GREEN LED | LED_THT:LED_D3.0mm | https://katalog.we-online.de/led/datasheet/151031SS04000.pdf | 732-5007-ND
D25 D26 D27 D28 | 4 | RED LED | LED_THT:LED_D3.0mm | https://katalog.we-online.de/led/datasheet/151031SS04000.pdf | 732-5005-ND
D31 D32 D33 D34 D35 D36 D37 D38 | 8 | BAT54J | Diode_SMD:D_SOD-323F | https://assets.nexperia.com/documents/data-sheet/BAT54J.pdf | 1727-4818-1-ND | C12744
J1 J2 J3 J4 J5 J7 J8 J9 J10 J11 | 10 | 3.5mm Jack | audio jacks:Jack_3.5mm_QingPu_WQP-PJ398SM_Vertical |  | WM17366-ND
J12 | 1 | Eurorack Power Cable |  |  | H3CCS-1618G-ND
J13 | 1 | Conn_01x02_Male | Connector_PinHeader_2.54mm:PinHeader_1x02_P2.54mm_Vertical |  |  | C2905434
J6 | 1 | 2x5 Header | Connector_PinHeader_2.54mm:PinHeader_2x05_P2.54mm_Vertical_SMD |  |  | C19268827
KN1 KN2 KN3 KN4 | 4 | Mult Knob |  |  | 1722-1314-ND
KN5 KN6 KN7 KN8 | 4 | CV Knob |  |  | 4654-FC7251-ND
Q2 | 1 | MMBT3904 | Package_TO_SOT_SMD:SOT-23 | https://www.onsemi.com/pub/Collateral/2N3903-D.PDF |  | C20526
Q3 | 1 | MMBT3906 | Package_TO_SOT_SMD:SOT-23 | https://www.onsemi.com/pub/Collateral/2N3906-D.PDF |  | C266589
R1 R2 R3 R4 R28 R44 R45 R48 R49 | 9 | 510 | Resistor_SMD:R_0805_2012Metric_Pad1.20x1.40mm_HandSolder |  | CRT0805-FZ-1002ELFCT-ND | C2842425
R10 R15 | 2 | 10K .1% | Resistor_SMD:R_0603_1608Metric |  | CRT0805-FZ-1002ELFCT-ND | C95204
R11 R16 | 2 | 100K | Resistor_SMD:R_0805_2012Metric_Pad1.20x1.40mm_HandSolder |  | CF14JT10K0CT-ND | C149504
R110 R111 R120 R121 | 4 | 120K | Resistor_SMD:R_0603_1608Metric |  | CF14JT10K0CT-ND | C25808
R113 R116 R123 R126 R134 R135 R137 R153 R154 R155 R156 R157 R158 R162 R163 R164 | 16 | 20K | Resistor_SMD:R_0603_1608Metric |  | CRT0805-FZ-1002ELFCT-ND | C4184
R12 R25 | 2 | 2K | Resistor_SMD:R_0603_1608Metric |  | CRT0805-FZ-1002ELFCT-ND | C22975
R13 | 1 | 88.7K | Resistor_SMD:R_0603_1608Metric |  | CRT0805-FZ-1002ELFCT-ND | C163418
R17 | 1 | 7.87K | Resistor_SMD:R_0603_1608Metric |  | CRT0805-FZ-1002ELFCT-ND | C103822
R174 R175 R176 R177 R186 R187 R188 R189 | 8 | 1M | Resistor_SMD:R_0603_1608Metric |  | CRT0805-FZ-1002ELFCT-ND | C22935
R178 R179 R180 R181 | 4 | 205K | Resistor_SMD:R_0603_1608Metric |  | CRT0805-FZ-1002ELFCT-ND | C22949
R18 | 1 | 3.65K | Resistor_SMD:R_0603_1608Metric_Pad0.98x0.95mm_HandSolder |  | CF14JT68K0CT-ND | C137730
R182 R183 R184 R185 | 4 | 2.55M | Resistor_SMD:R_0603_1608Metric |  | CRT0805-FZ-1002ELFCT-ND | C422950
R19 | 1 | 5.1K | Resistor_SMD:R_0603_1608Metric |  | CRT0805-FZ-1002ELFCT-ND | C23186
R190 | 1 | 100K | Resistor_SMD:R_0603_1608Metric |  | CRT0805-FZ-1002ELFCT-ND | C25803
R20 R23 | 2 | 16.5K | Resistor_SMD:R_0603_1608Metric |  | CRT0805-FZ-1002ELFCT-ND | C227613
R21 | 1 | 620 | Resistor_SMD:R_0805_2012Metric_Pad1.20x1.40mm_HandSolder |  | CF14JT68K0CT-ND | C144551
R136 R140 R159 R160 R161 R171 R172 R173 R215 | 9 | 4.7K | Resistor_SMD:R_0603_1608Metric |  | CRT0805-FZ-1002ELFCT-ND | C23162
R22 | 1 | 200K | Resistor_SMD:R_0805_2012Metric_Pad1.20x1.40mm_HandSolder |  | CF14JT10K0CT-ND | C17539
R24 R27 | 2 | 68K | Resistor_SMD:R_0805_2012Metric_Pad1.20x1.40mm_HandSolder |  | CF14JT10K0CT-ND | C17801
R26 | 1 | 59K | Resistor_SMD:R_0603_1608Metric |  | CRT0805-FZ-1002ELFCT-ND | C218088
R29 R118 R119 R128 R129 R131 R132 R138 R139 R142 R144 R146 R147 R148 R149 R165 R166 R167 R168 R169 R170 R211 R212 R213 R214 | 25 | 1K | Resistor_SMD:R_0603_1608Metric |  | CRT0805-FZ-1002ELFCT-ND | C21190
R33 R35 R37 R40 R52 R54 R82 R84 | 8 | 27K | Resistor_SMD:R_0805_2012Metric_Pad1.20x1.40mm_HandSolder |  | CF14JT10K0CT-ND | C17593
R34 R36 R38 R41 R53 R55 R83 R85 | 8 | 1.5K | Resistor_SMD:R_0805_2012Metric_Pad1.20x1.40mm_HandSolder |  | CF14JT10K0CT-ND | C4310
R46 R47 R218 R219 | 4 | 12K | Resistor_SMD:R_0603_1608Metric |  | CRT0805-FZ-1002ELFCT-ND | C22790
R5 R6 R7 R8 R9 R14 R30 R31 R32 R39 R42 R43 R50 R51 R80 R81 R130 R133 R141 R143 R145 R150 R151 R152 R216 R217 | 26 | 10K | Resistor_SMD:R_0603_1608Metric |  | CRT0805-FZ-1002ELFCT-ND | C25804
R56 R62 R86 R91 | 4 | 162K | Resistor_SMD:R_0603_1608Metric |  | CF14JT10K0CT-ND | C217756
R57 R63 R87 R92 | 4 | 154K | Resistor_SMD:R_0603_1608Metric |  | CF14JT10K0CT-ND | C321731
R58 R64 R88 R93 R112 R115 R122 R125 | 8 | 210K | Resistor_SMD:R_0603_1608Metric |  | CF14JT10K0CT-ND | C227705
R59 R65 R89 R94 | 4 | 300K | Resistor_SMD:R_0603_1608Metric |  | CF14JT10K0CT-ND | C23024
R60 R61 R90 R95 | 4 | 237K | Resistor_SMD:R_0603_1608Metric |  | CF14JT10K0CT-ND | C403089
R66 R73 R96 R102 R114 R117 R124 R127 | 8 | 150K | Resistor_SMD:R_0603_1608Metric |  | CF14JT10K0CT-ND | C22807
R67 R74 R97 R103 | 4 | 174K | Resistor_SMD:R_0603_1608Metric |  | CF14JT10K0CT-ND | C2933159
R68 R75 R98 R104 | 4 | 261K | Resistor_SMD:R_0603_1608Metric |  | CF14JT10K0CT-ND | C2930083
R69 R76 R99 R105 | 4 | 287K | Resistor_SMD:R_0603_1608Metric |  | CF14JT10K0CT-ND | C5159700
R70 R72 R100 R106 | 4 | 191K | Resistor_SMD:R_0603_1608Metric |  | CF14JT10K0CT-ND | C321771
R71 R77 R101 R107 | 4 | 200K | Resistor_SMD:R_0603_1608Metric |  | CF14JT10K0CT-ND | C25811
R78 R79 R108 R109 | 4 | 52.3K | Resistor_SMD:R_0603_1608Metric |  | CF14JT10K0CT-ND | C23198
RV1 | 1 | 500 | Potentiometer_SMD:Potentiometer_Bourns_3224W_Vertical | https://www.bourns.com/docs/Product-Datasheets/TC33.pdf |  | C116324
RV10 RV11 RV14 RV15 | 4 | 1K | Potentiometer_THT:Potentiometer_Bourns_PTV09A-1_Single_Vertical |  | PTV09A-4020F-B102-ND
RV12 RV13 RV16 RV17 | 4 | 5K | Potentiometer_SMD:Potentiometer_Bourns_3224W_Vertical | https://www.bourns.com/docs/Product-Datasheets/TC33.pdf |  | C81349
RV2 RV3 RV4 RV5 RV6 RV7 RV8 RV9 | 8 | 50K | sputterizer:HDK_3mm | https://www.bourns.com/docs/Product-Datasheets/TC33.pdf | 118-TC33X-1-503ECT-ND | C913246
SC2 SC4 SC6 SC8 | 4 | Mounting Screw |  |  | 335-1156-ND
SO1 SO2 SO3 SO4 SO5 | 5 | LED Spacer 9mm |  |  | RPC4262-ND
SW1 SW2 SW3 SW8 | 4 | SW_Rotary8 | sputterizer:CPA_8 | http://cdn-reichelt.de/documents/datenblatt/C200/DS-Serie%23LOR.pdf | 1528-2925-ND
SW4 SW5 SW6 SW7 | 4 | SW_SPDT | digikey-footprints:Toggle_Switch_100SP1T1B4M2QE |  | 2449-ANT11SF1CQE-ND
TP1 TP2 TP3 TP4 TP5 TP6 TP7 TP12 TP20 TP21 TP23 TP24 | 12 | TestPoint | TestPoint:TestPoint_Loop_D2.54mm_Drill1.5mm_Beaded |  | 36-5006-ND | C5199801
U1 U3 U5 U16 U17 U22 U23 U28 U29 U32 U33 | 11 | TL072CP | Package_SO:SOIC-8_3.9x4.9mm_P1.27mm |  | 296-1775-5-ND | C6961
U12 U13 | 2 | CD4013 | Package_SO:SOIC-14_3.9x8.7mm_P1.27mm | http://www.onsemi.com/pub/Collateral/MC14013B-D.PDF | 296-24347-1-ND | C13527
U2 U36 U38 U39 U40 U44 U45 U46 | 8 | TL071 | Package_TO_SOT_SMD:SOT-353_SC-70-5 | http://www.ti.com/lit/ds/symlink/tlv172.pdf | 296-TL071HIDCKRCT-ND | C4370475
U30 U31 U34 U35 | 4 | NSL-32SR3 | sputterizer:NSL-32SR3 | http://www.qsl.net/wa1ion/vactrol/vactrol.pdf | NSL-32SR3-ND
U37 U41 U42 U43 | 4 | LM13700 | Package_SO:SOIC-16_3.9x9.9mm_P1.27mm | http://www.ti.com/lit/ds/symlink/lm13700.pdf |  | C174050
U4 | 1 | LM317_SOT-223 | Package_TO_SOT_SMD:SOT-223-3_TabPin2 | http://www.ti.com/lit/ds/symlink/lm317.pdf |  | C347367
U6 U7 U8 U14 U18 U19 U24 U25 | 8 | CD4046 | Package_SO:TSSOP-16_4.4x5mm_P0.65mm | https://assets.nexperia.com/documents/data-sheet/HEF4046B.pdf | 296-32888-5-ND | C2651240
U9 U10 U11 U15 U20 U21 U26 U27 | 8 | CD4017 | Package_SO:SOIC-16_3.9x9.9mm_P1.27mm | http://www.intersil.com/content/dam/Intersil/documents/cd40/cd4017bms-22bms.pdf | 296-12808-1-ND | C356694

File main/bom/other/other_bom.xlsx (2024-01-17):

Reference | Quantity | Value | URL
M1 | 1 | OLED | https://www.amazon.com/gp/product/B072Q2X2LL/

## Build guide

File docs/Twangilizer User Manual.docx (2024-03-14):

# Twangilizer User Manual

## Description:

The Twangilizer is a Eurorack module that fits in a 3U x 20HP format. It is an “additive synthesis” module that generates four sine waves that are harmonically related to a given input signal.

Using the 8-position rotary switches the user can select from 8 harmonics (1f – 8f). The resulting signals can be used as-is or can be halved in frequency by the toggle switches. This gives the user many interesting options when creating a sound.

The levels of the resulting harmonics are set by VCAs that are controlled by the front panel potentiometers and the CV inputs. An indicator LED displays the level of the adjustment.

## Inputs:

1. Clock input. Accepts signals > .25Vpp. 20 – 20KHz.
2. CV1 – CV4. Control the level of the harmonics sent to analog out. 0-8V range.

## Outputs:

1. Analog Out. Sum of all four harmonics.
2. CLK Outputs 1-4. Digital outputs of the four harmonics. For syncing other modules.

## Controls:

1. Four Harmonic Selectors – Select from 1f through 8f.
2. Four Harmonic divide-by-two selectors – Select f/1 or f/2
3. Four CV Bias controls – Controls initial level of each harmonic.

## Indicators:

1. Clock Present Indicator – Glows Green when a Clock signal is present.
2. Four CV level indicators. – Red LED intensity shows CV level.

## Uses:

1. Use a VCO and the CV bias settings to create unique timbre profiles.
2. Use a VCO and a triggered multiple envelope generator connected to the CV inputs to create dynamically changing timbre profiles.
3. Use a VCO to create a multiple clock generator at the Digital Outputs.
4. Use multiple Twangilizers in various topologies employing the above techniques to create ultra-complex timbre profiles and different clock frequencies.

# CV Curves

The 3 graphs below show the output level of the VCAs in volts peak-to-peak vs. the CV Input voltage at various CV Bias settings.

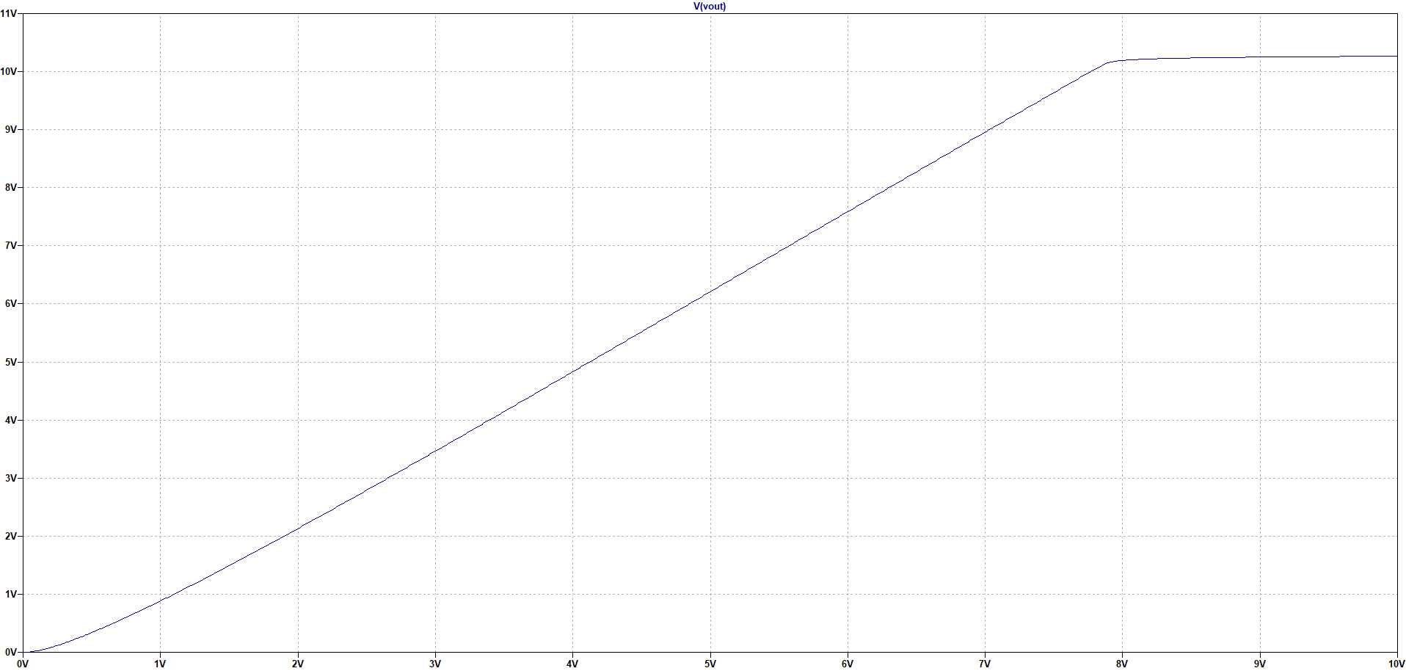
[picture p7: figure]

Figure 1 CV Bias at 0%

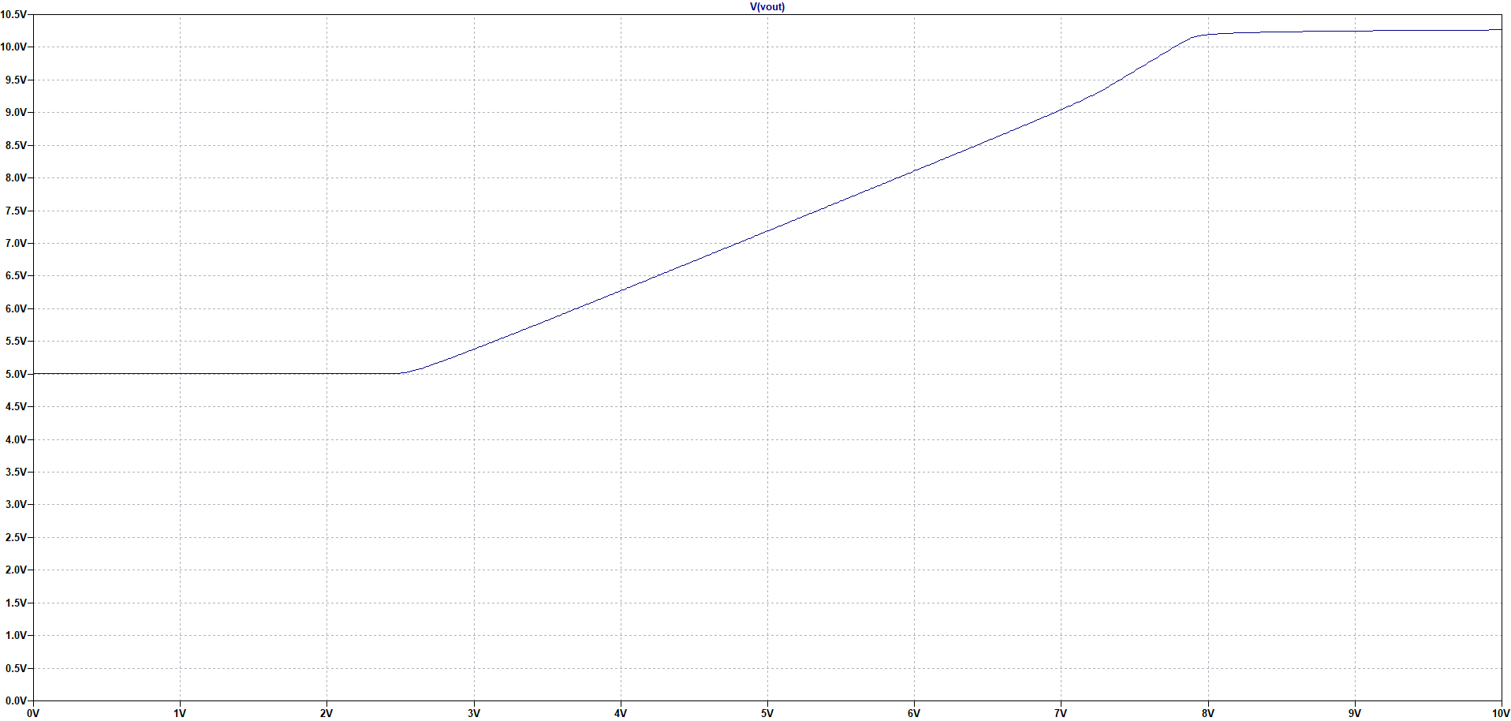
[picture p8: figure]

Figure 2 CV Bias at 50%

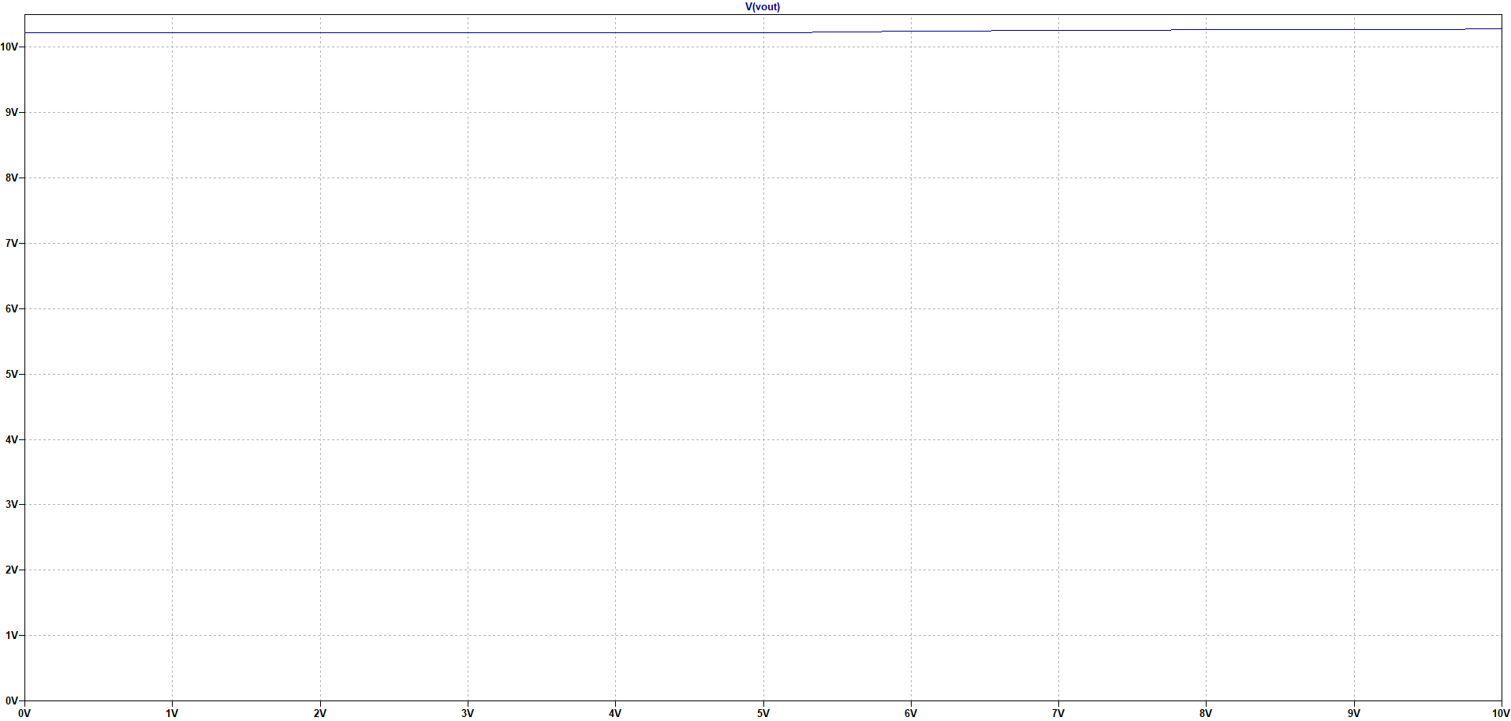
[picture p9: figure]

Figure 3 CV Bias at 100%

## Front Panel:

(actual panel will differ slightly)

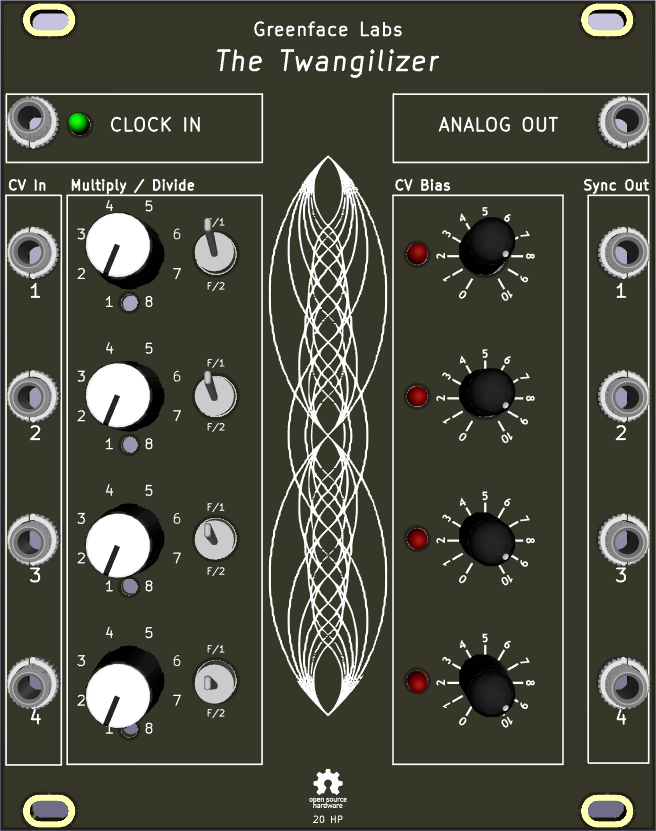
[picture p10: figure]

## Notes:

1. The Greenface Labs Bonkulator is the ideal multiple envelope generator. Having 8 triggered outputs, it can devote 4 to the Twangilizer and another 4 to other modules.
2. Because the Twangilizer uses phase locked loops, a portamento effect is normal.
3. All inputs and outputs are protected against ESD and over-voltage. (+/-25V continuous, protection diodes have PN Junction Guard Ring for Transient and ESD Protection).

Greenface Labs - 2024

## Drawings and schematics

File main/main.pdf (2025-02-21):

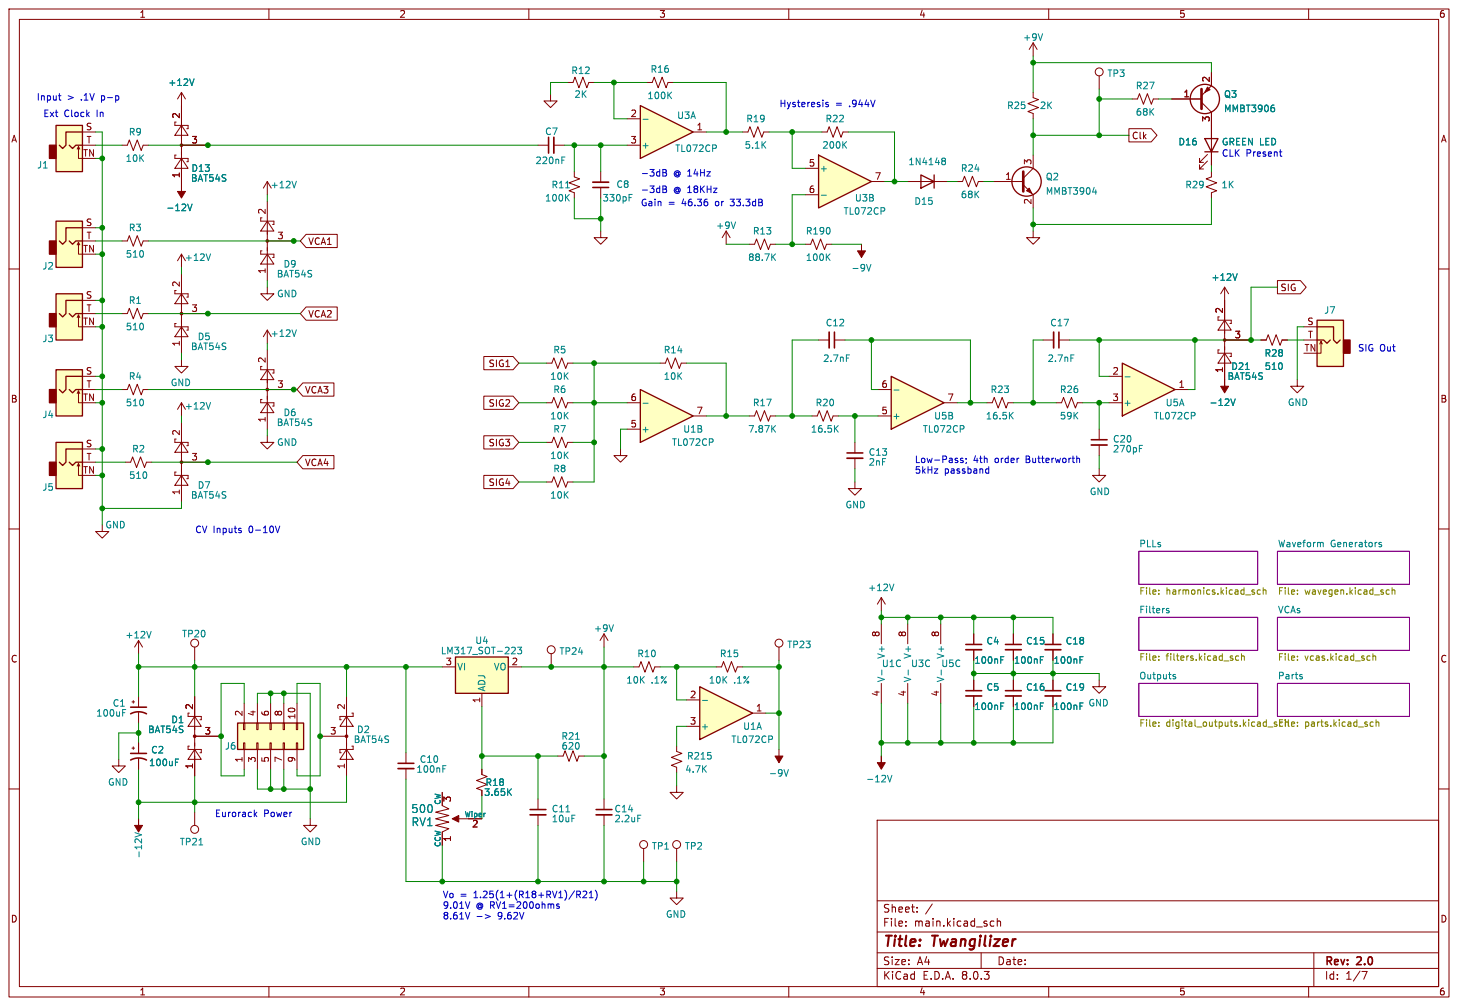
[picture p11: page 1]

Input > .1V p-p Ext Clock In

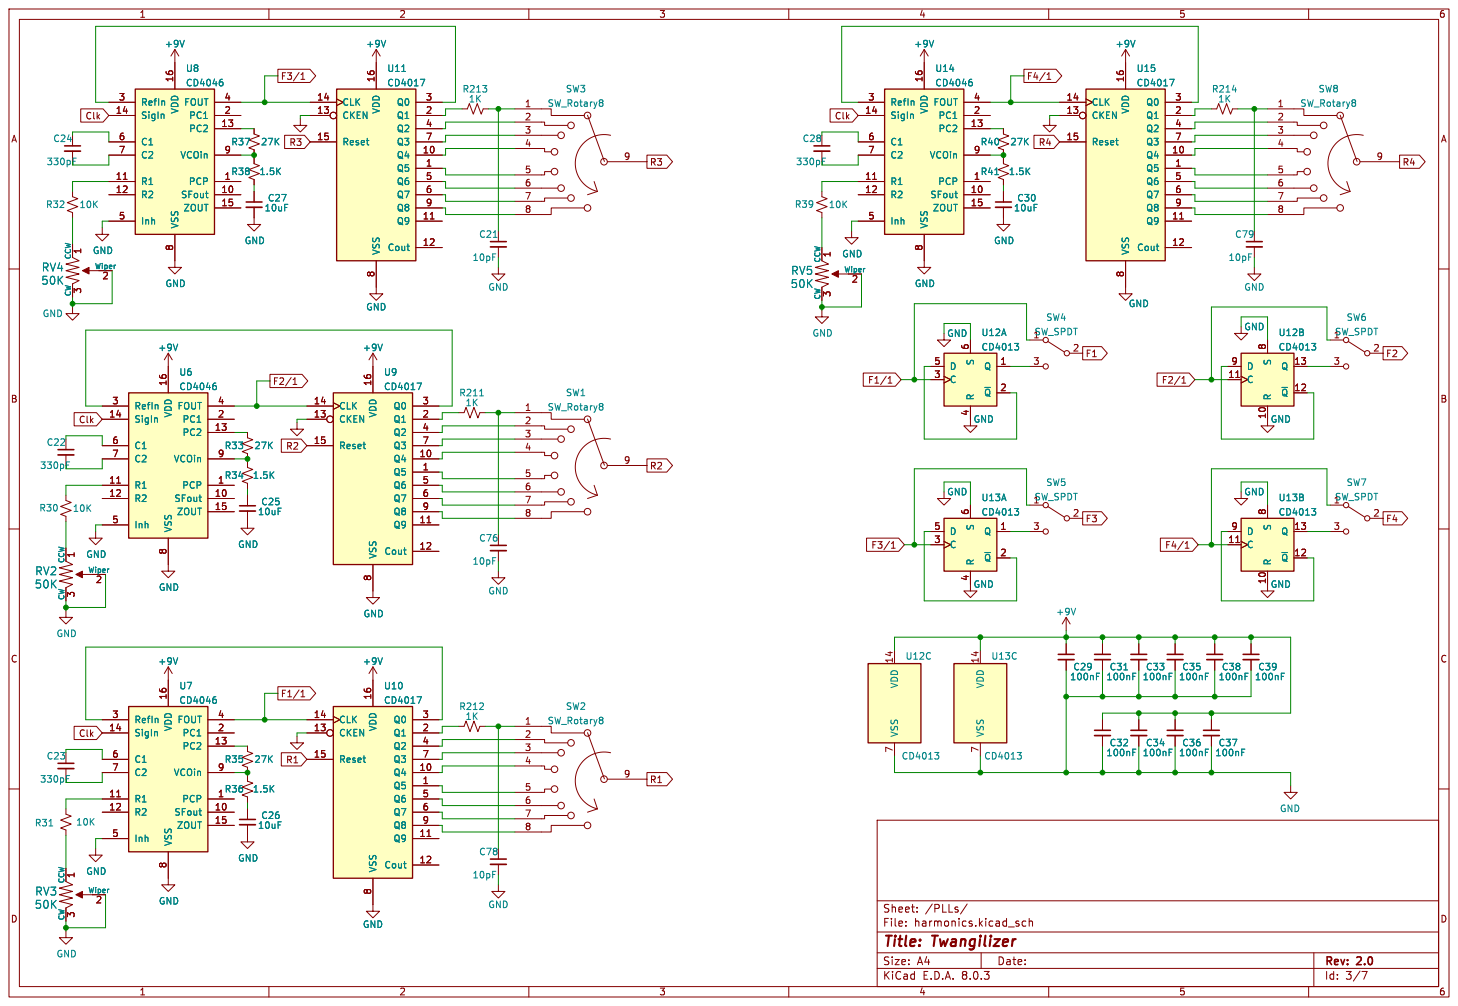
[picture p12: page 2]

Id: 3/7 Title: Twangilizer File: harmonics.kicad_sch Sheet: /PLLs/

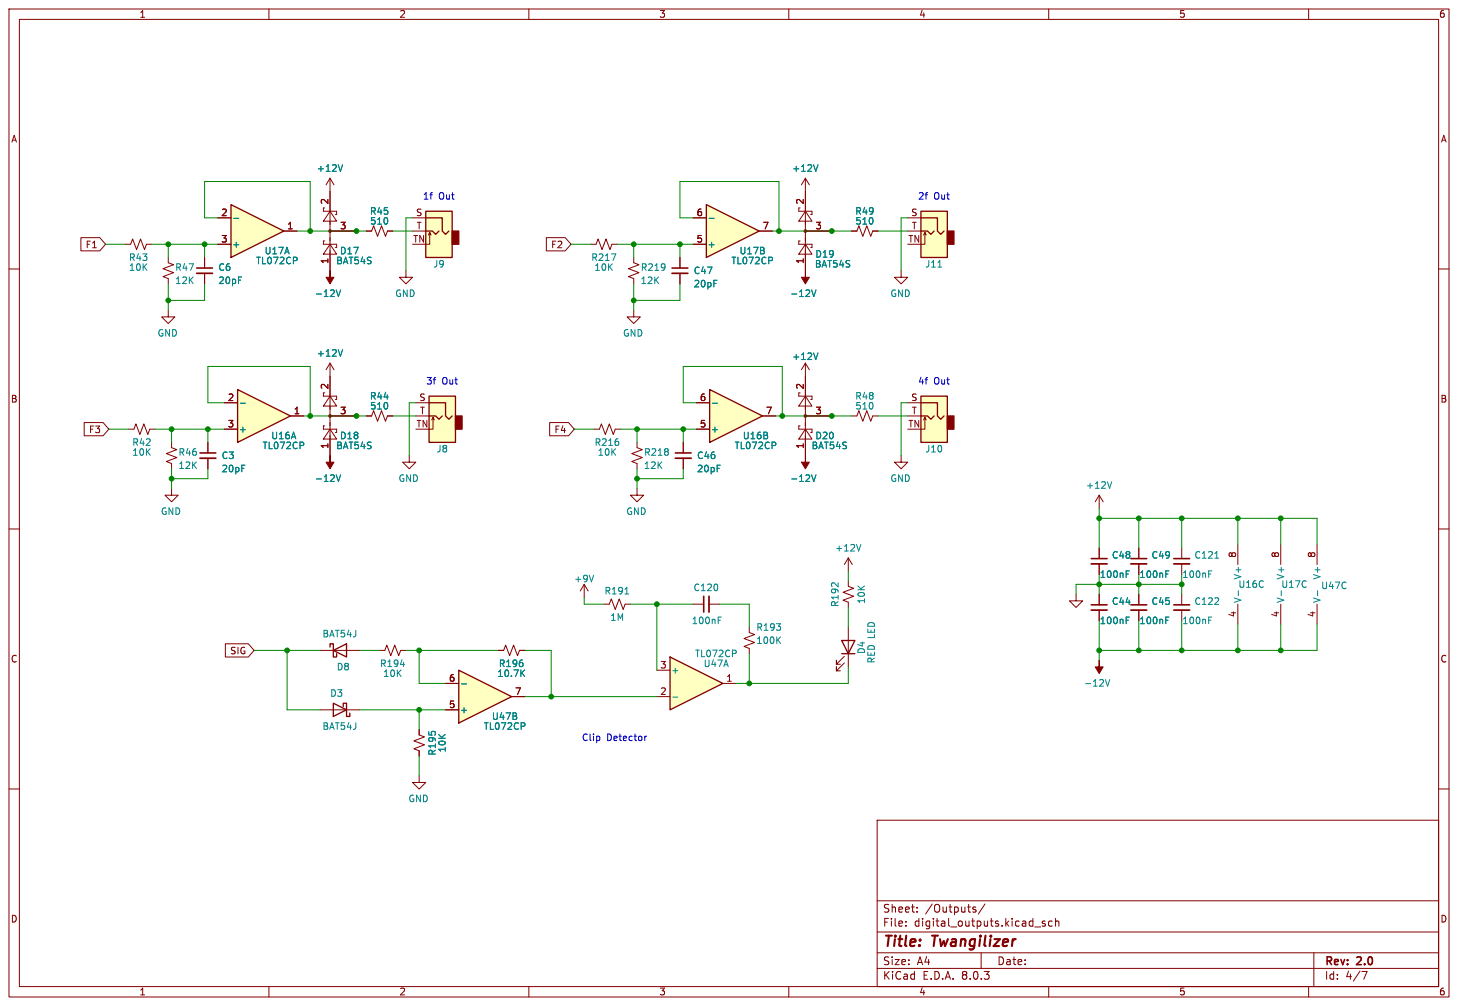
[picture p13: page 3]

Id: 4/7 Title: Twangilizer File: digital_outputs.kicad_sch Sheet: /Outputs/

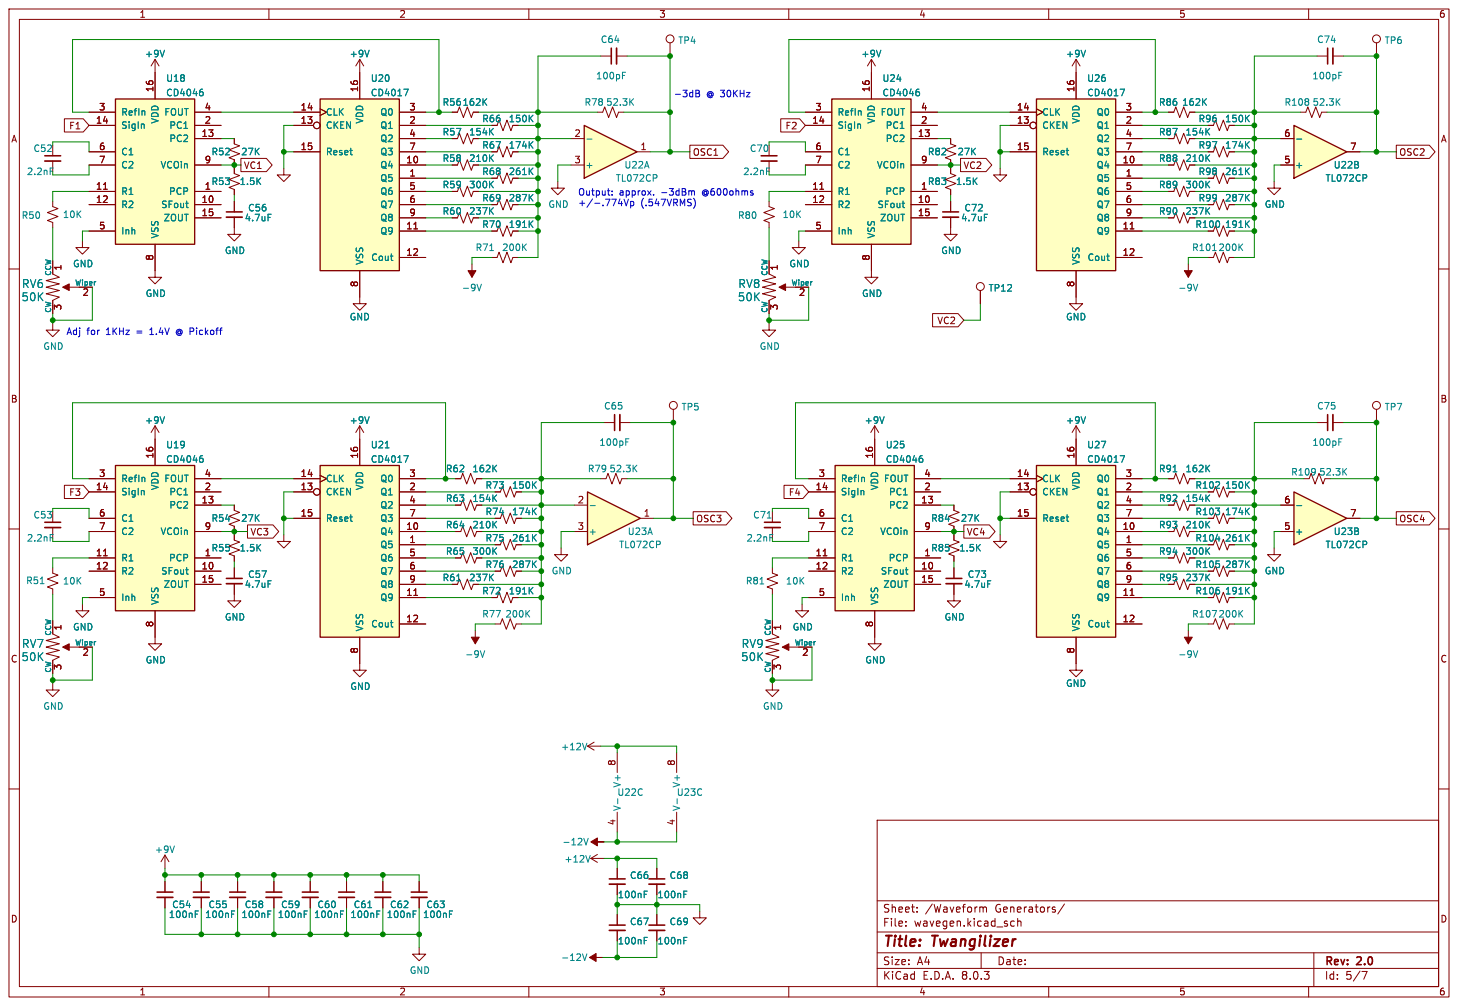
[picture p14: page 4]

8 VCOin 9 U18 CD4046 PCP 1 SFout 10 R1 11 R2 12 PC2 13 SigIn 14 ZOUT 15 VDD 16 PC1 2 RefIn 3 FOUT 4

8 VCOin 9 U19 CD4046 PCP 1 SFout 10 R1 11 R2 12 PC2 13 SigIn 14 ZOUT 15 VDD 16 PC1 2 RefIn 3 FOUT 4

8 Q8 9 U21 CD4017 PCP 1 SFout 10 R1 11 R2 12 PC2 13 SigIn 14 ZOUT 15 VDD 16 PC1 2 RefIn 3 FOUT 4

8 Q8 9 U19 CD4046 PCP 1 SFout 10 R1 11 R2 12 PC2 13 SigIn 14 ZOUT 15 VDD 16 PC1 2 RefIn 3 FOUT 4

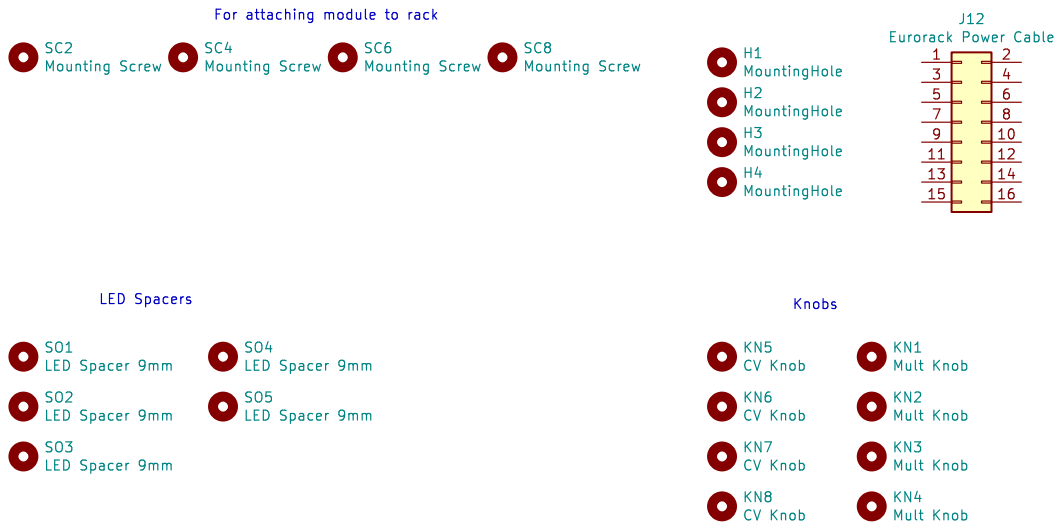
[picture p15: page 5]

Id: 5/7 Title: Twangilizer File: parts.kicad_sch Sheet: /Parts/

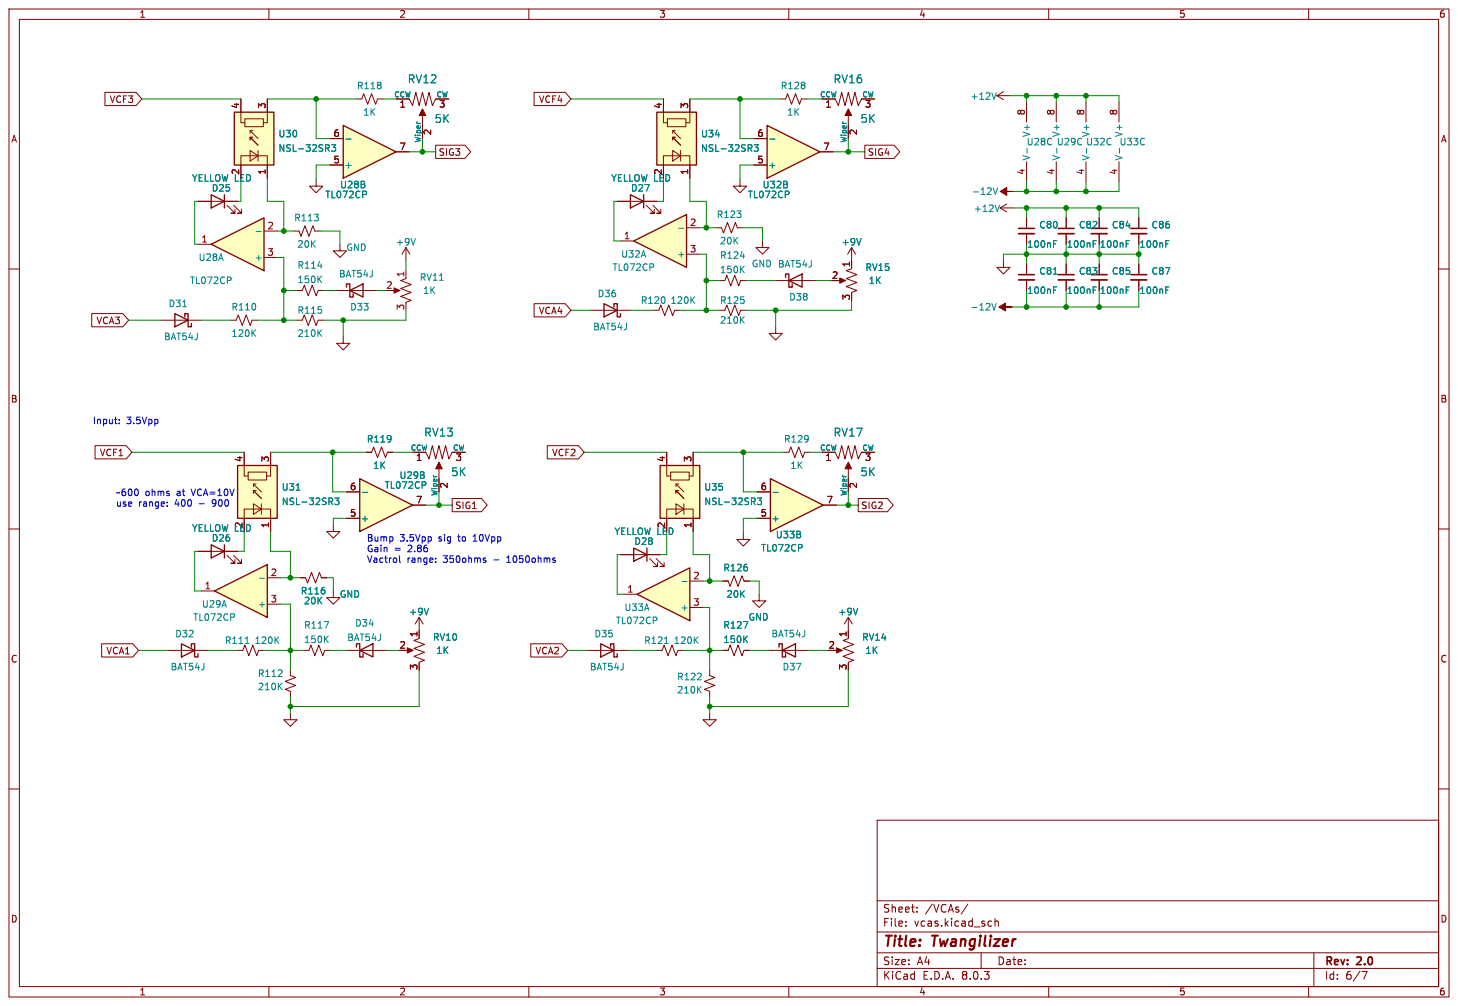
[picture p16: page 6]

Input: 3.5Vpp ~600 ohms at VCA=10V

Id: 6/7 Title: Twangilizer File: vcas.kicad_sch Sheet: /VCAs/

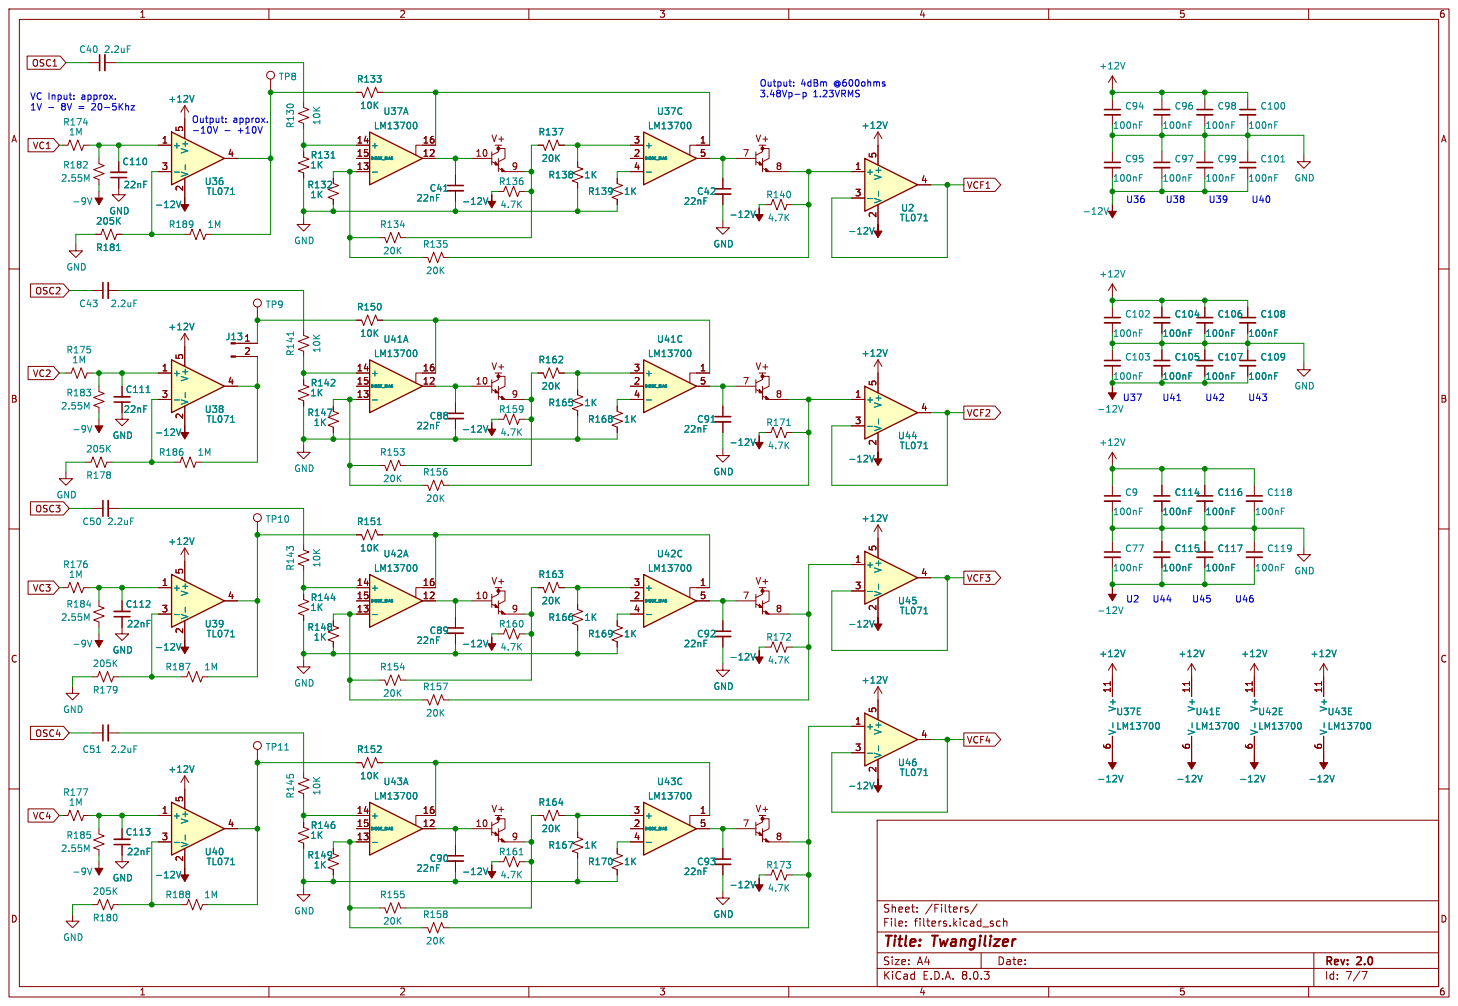
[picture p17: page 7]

Id: 7/7 Title: Twangilizer File: filters.kicad_sch Sheet: /Filters/

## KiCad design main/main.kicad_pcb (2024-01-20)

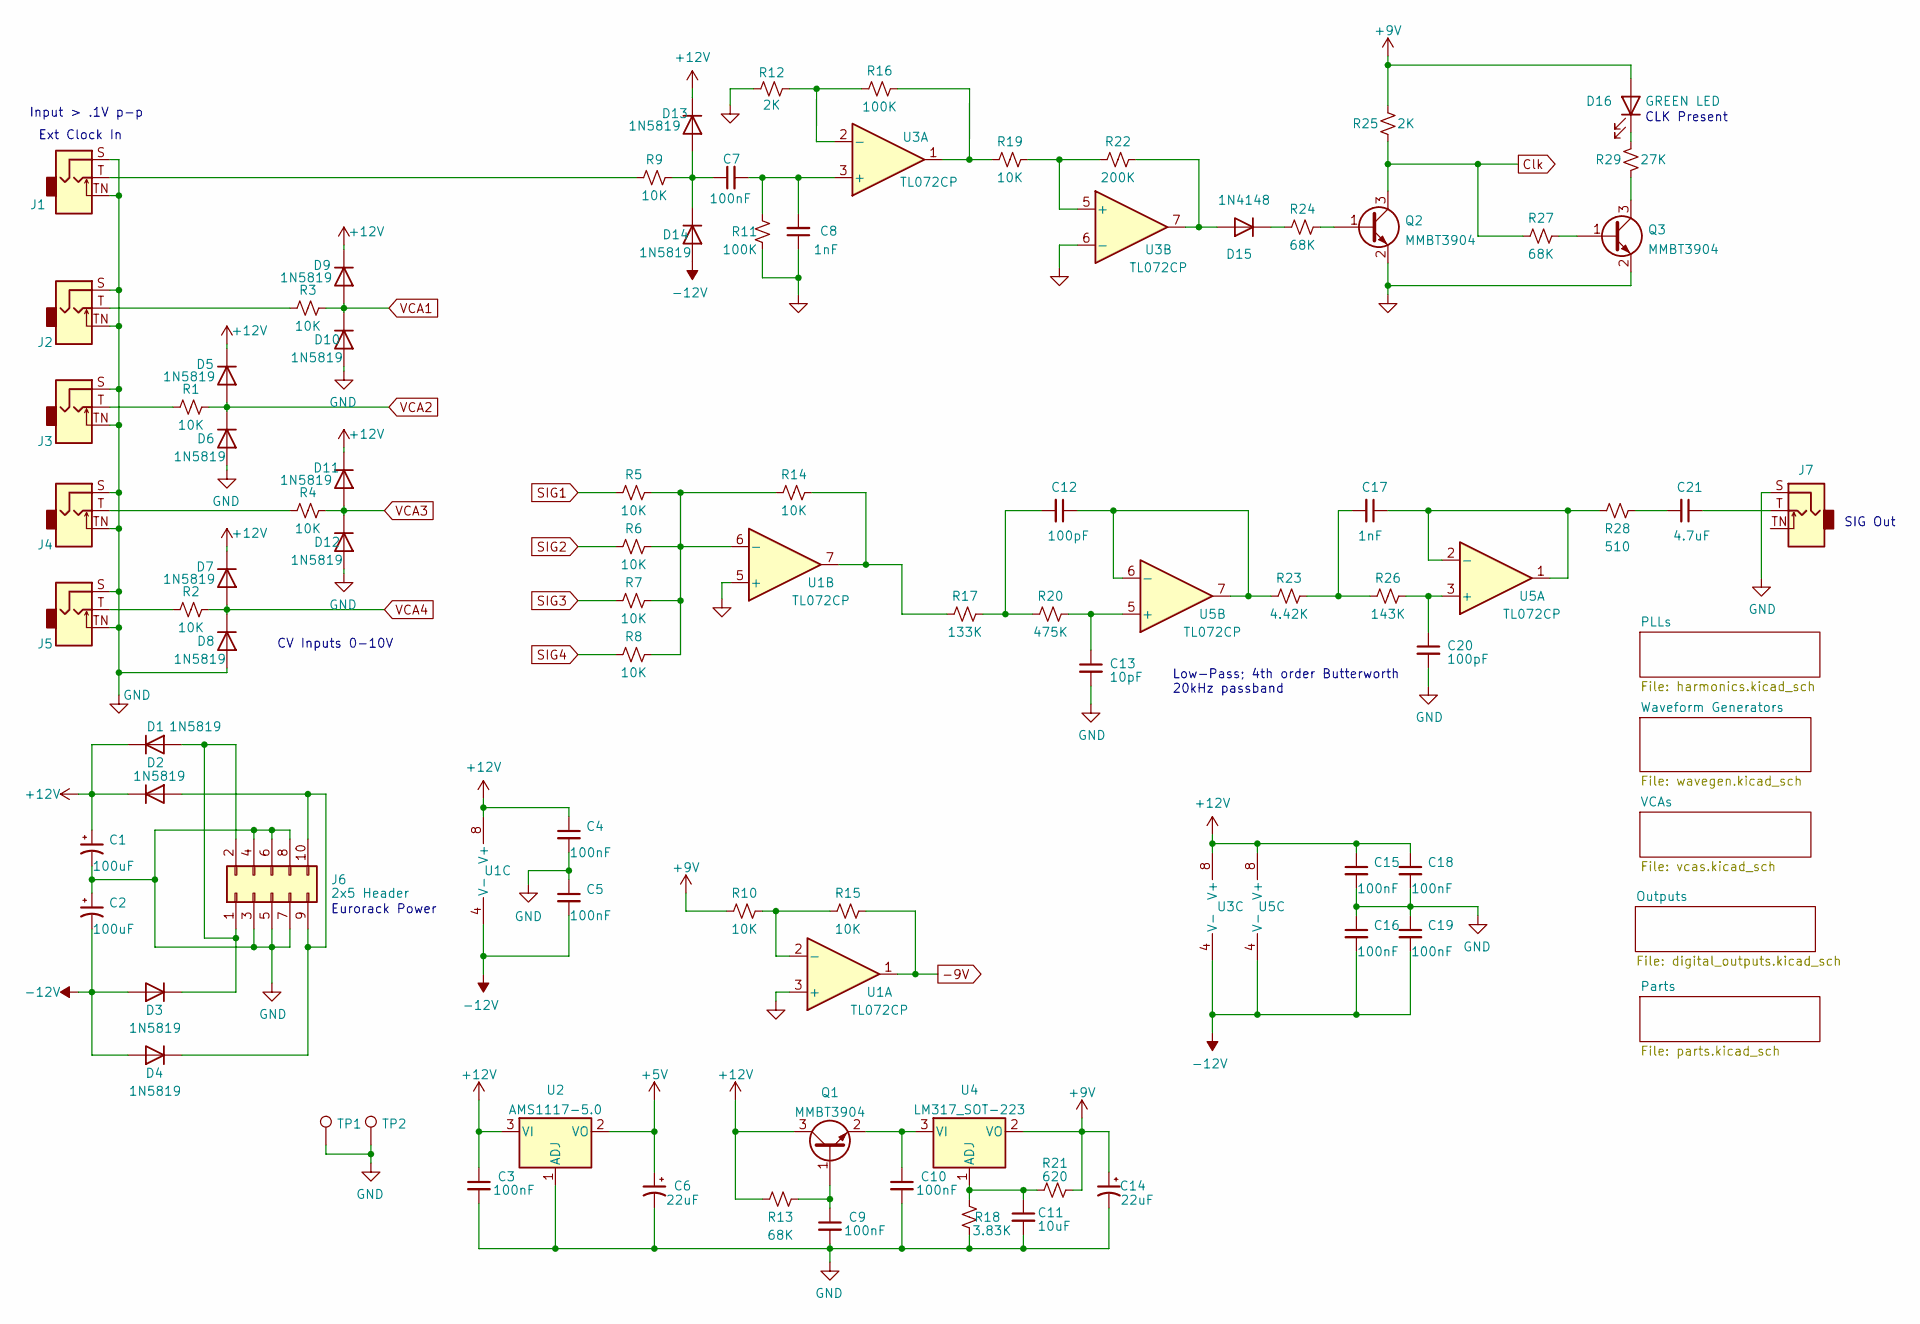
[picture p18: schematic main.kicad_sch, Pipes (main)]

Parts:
C1, C2: 100uF; CP_Elec_6.3x5.4_Nichicon; Digi-Key Part 399-EDH107M016A9GAACT-ND
C3, C4, C5, C7, C9, C10, C15, C16, C18, C19: 100nF; C_0805_2012Metric_Pad1.18x1.45mm_HandSolder; Digi-Key Part 478-10836-1-ND
C6, C14: 22uF; CP_EIA-3216-18_Kemet-A; Digi-Key Part 478-12960-1-ND
C8, C17: 1nF; C_0805_2012Metric_Pad1.18x1.45mm_HandSolder; Digi-Key Part 399-9877-1-ND
C11: 10uF; C_0805_2012Metric_Pad1.18x1.45mm_HandSolder; Digi-Key Part 399-9886-1-ND
C12, C20: 100pF; C_0805_2012Metric_Pad1.18x1.45mm_HandSolder; Digi-Key Part 399-9877-1-ND
C13: 10pF; C_0603_1608Metric_Pad1.08x0.95mm_HandSolder; Digi-Key Part 399-9877-1-ND
C21: 4.7uF; C_1206_3216Metric; Digi-Key Part 399-9877-1-ND
D1, D2, D3, D4, D5, D6, D7, D8, D9, D10, D11, D12, D13, D14: 1N5819; D_SOD-323_HandSoldering; Digi-Key Part 478-7800-1-ND
D15: 1N4148; D_SOD-123; Digi-Key Part 1N4148VSCT-ND
D16: GREEN LED; LED_D3.0mm; Digi-Key Part 732-5007-ND
J1, J2, J3, J4, J5, J7: 3.5mm Jack; Jack_3.5mm_QingPu_WQP-PJ398SM_Vertical; Digi-Key Part WM17366-ND
J6: 2x5 Header; PinHeader_2x05_P2.54mm_Vertical_SMD; LCSC Part # C124391
Q1, Q2, Q3: MMBT3904; SOT-23; LCSC Part # C20526
R1, R2, R3, R4, R5, R6, R7, R8, R9, R10, R14, R15, R19: 10K; R_0603_1608Metric; Digi-Key Part CRT0805-FZ-1002ELFCT-ND
R11, R16: 100K; R_0805_2012Metric_Pad1.20x1.40mm_HandSolder; Digi-Key Part CF14JT10K0CT-ND
R12, R25: 2K; R_0603_1608Metric; Digi-Key Part CRT0805-FZ-1002ELFCT-ND
R13: 68K; R_0805_2012Metric_Pad1.20x1.40mm_HandSolder; Digi-Key Part CF14JT68K0CT-ND
R17: 133K; R_0603_1608Metric; Digi-Key Part CRT0805-FZ-1002ELFCT-ND
R18: 3.83K; R_0805_2012Metric_Pad1.20x1.40mm_HandSolder; Digi-Key Part CF14JT68K0CT-ND
R20: 475K; R_0603_1608Metric; Digi-Key Part CRT0805-FZ-1002ELFCT-ND
R21: 620; R_0805_2012Metric_Pad1.20x1.40mm_HandSolder; Digi-Key Part CF14JT68K0CT-ND
R22: 200K; R_0805_2012Metric_Pad1.20x1.40mm_HandSolder; Digi-Key Part CF14JT10K0CT-ND
R23: 4.42K; R_0603_1608Metric; Digi-Key Part CRT0805-FZ-1002ELFCT-ND
R24, R27: 68K; R_0805_2012Metric_Pad1.20x1.40mm_HandSolder; Digi-Key Part CF14JT10K0CT-ND
R26: 143K; R_0603_1608Metric; Digi-Key Part CRT0805-FZ-1002ELFCT-ND
R28: 510; R_0805_2012Metric_Pad1.20x1.40mm_HandSolder; Digi-Key Part PPC470W-1CT-ND
R29: 27K; R_0805_2012Metric_Pad1.20x1.40mm_HandSolder; Digi-Key Part CRT0805-FZ-1002ELFCT-ND
TP1, TP2: TestPoint; TestPoint_Keystone_5005-5009_Compact; Digi-Key Part 36-5006-ND
U1, U3, U5: TL072CP; SOIC-8_3.9x4.9mm_P1.27mm; Digi-Key Part 296-1775-5-ND
U2: AMS1117-5.0; SOT-223-3_TabPin2; LCSC Part # C6187
U4: LM317_SOT-223; SOT-223-3_TabPin2; LCSC Part # C347367

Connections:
+5V: C6.1, U2.2 (VO); also elsewhere on the board
+9V: C14.1, D16.2 (A), R10.2, R21.1, R25.1, U4.2 (VO); also elsewhere on the board
+12V: C1.1, C3.1, C4.1, C15.1, C18.1, D1.1 (K), D2.1 (K), D5.1 (K), D7.1 (K), D9.1 (K), D11.1 (K), D13.1 (K), Q1.3 (C), R13.2, U1.8 (V+), U2.3 (VI), U3.8 (V+), U5.8 (V+); also elsewhere on the board
-9V: R15.1, U1.1; also elsewhere on the board
-12V: C2.2, C5.2, C16.2, C19.2, D3.2 (A), D4.2 (A), D14.2 (A), U1.4 (V-), U3.4 (V-), U5.4 (V-); also elsewhere on the board
Clk: Q2.3 (C), R25.2, R27.2; also elsewhere on the board
GND: C1.2, C2.1, C3.2, C4.2, C5.1, C6.2, C8.1, C9.2, C10.2, C11.2, C13.2, C14.2, C15.2, C16.1, C18.2, C19.1, C20.2, D6.2 (A), D8.2 (A), D10.2 (A), D12.2 (A), J1.S, J1.TN, J2.S, J2.TN, J3.S, J3.TN, J4.S, J4.TN, J5.S, J5.TN, J6.3, J6.4, J6.5, J6.6, J6.7, J6.8, J7.S, Q2.2 (E), Q3.2 (E), R11.2, R12.1, R18.2, TP1.1, TP2.1, U1.3 (+), U1.5 (+), U2.1 (ADJ), U3.6 (-); also elsewhere on the board
unnamed: C7.1, D13.2 (A), D14.1 (K), R9.1
unnamed: C7.2, C8.2, R11.1, U3.3 (+)
unnamed: C9.1, Q1.1 (B), R13.1
unnamed: C10.1, Q1.2 (E), U4.3 (VI)
unnamed: C11.1, R18.1, R21.2, U4.1 (ADJ)
unnamed: C12.1, R23.2, U5.6 (-), U5.7
unnamed: C12.2, R17.1, R20.2
unnamed: C13.1, R20.1, U5.5 (+)
unnamed: C17.1, R28.1, U5.1, U5.2 (-)
unnamed: C17.2, R23.1, R26.2
unnamed: C20.1, R26.1, U5.3 (+)
unnamed: C21.1, J7.T
unnamed: C21.2, R28.2
unnamed: D1.2 (A), D3.1 (K), J6.1, J6.2
unnamed: D2.2 (A), D4.1 (K), J6.9, J6.10
unnamed: D15.1 (K), R24.2
unnamed: D15.2 (A), R22.1, U3.7
unnamed: D16.1 (K), R29.2
unnamed: J1.T, R9.2
unnamed: J2.T, R3.2
unnamed: J3.T, R1.2
unnamed: J4.T, R4.2
unnamed: J5.T, R2.2
unnamed: Q2.1 (B), R24.1
unnamed: Q3.1 (B), R27.1
unnamed: Q3.3 (C), R29.1
unnamed: R10.1, R15.2, U1.2 (-)
unnamed: R12.2, R16.2, U3.2 (-)
unnamed: R14.1, R17.2, U1.7
unnamed: R5.1, R6.1, R7.1, R8.1, R14.2, U1.6 (-)
unnamed: R16.1, R19.2, U3.1
unnamed: R19.1, R22.2, U3.5 (+)
SIG1: R5.2; also elsewhere on the board
SIG2: R6.2; also elsewhere on the board
SIG3: R7.2; also elsewhere on the board
SIG4: R8.2; also elsewhere on the board
VCA1: D9.2 (A), D10.1 (K), R3.1; also elsewhere on the board
VCA2: D5.2 (A), D6.1 (K), R1.1; also elsewhere on the board
VCA3: D11.2 (A), D12.1 (K), R4.1; also elsewhere on the board
VCA4: D7.2 (A), D8.1 (K), R2.1; also elsewhere on the board

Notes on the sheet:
Eurorack Power
SIG Out
Low-Pass; 4th order Butterworth 20kHz passband
Input > .1V p-p
CLK Present
CV Inputs 0-10V
Ext Clock In

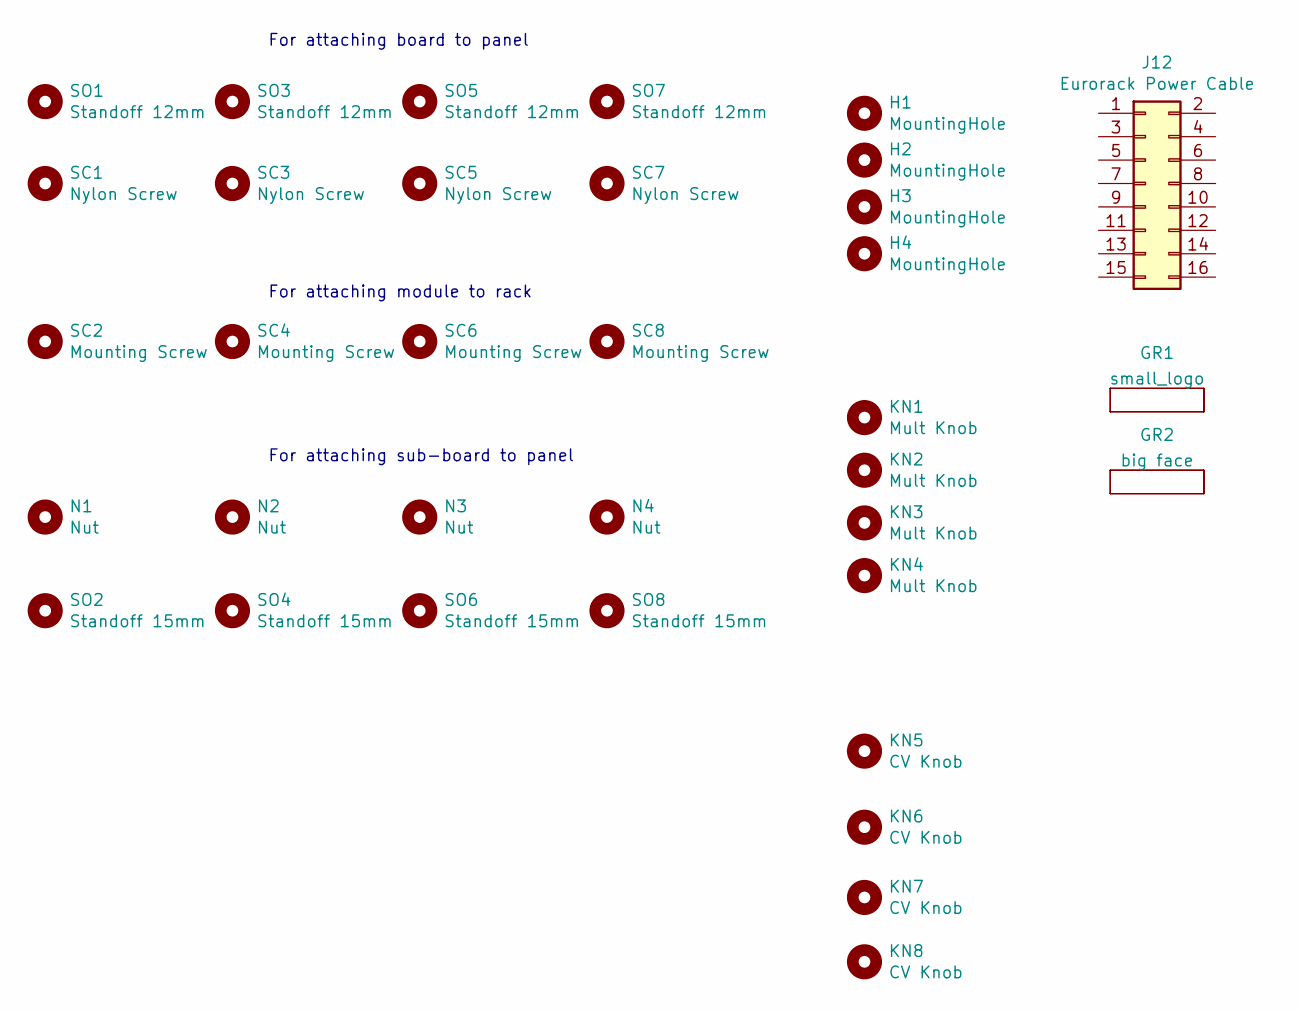
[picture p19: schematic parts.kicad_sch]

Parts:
GR1: small_logo; small_face
GR2: big face; face_logo
H1, H2, H3, H4: MountingHole; MountingHole_2.5mm
J12: Eurorack Power Cable; Digi-Key Part H3CCS-1618G-ND
KN1, KN2, KN3, KN4: Mult Knob; Digi-Key Part 1722-1314-ND
KN5, KN6, KN7, KN8: CV Knob; Digi-Key Part 4654-FC7251-ND
N1, N2, N3, N4: Nut; Digi-Key Part 36-4687-ND
SC1, SC3, SC5, SC7: Nylon Screw; Digi-Key Part 36-29331-ND
SC2, SC4, SC6, SC8: Mounting Screw; Digi-Key Part 335-1156-ND
SO1, SO3, SO5, SO7: Standoff 12mm; Digi-Key Part 732-13063-ND
SO2, SO4, SO6, SO8: Standoff 15mm; Digi-Key Part 732-13072-ND

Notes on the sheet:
For attaching module to rack
For attaching board to panel
For attaching sub-board to panel

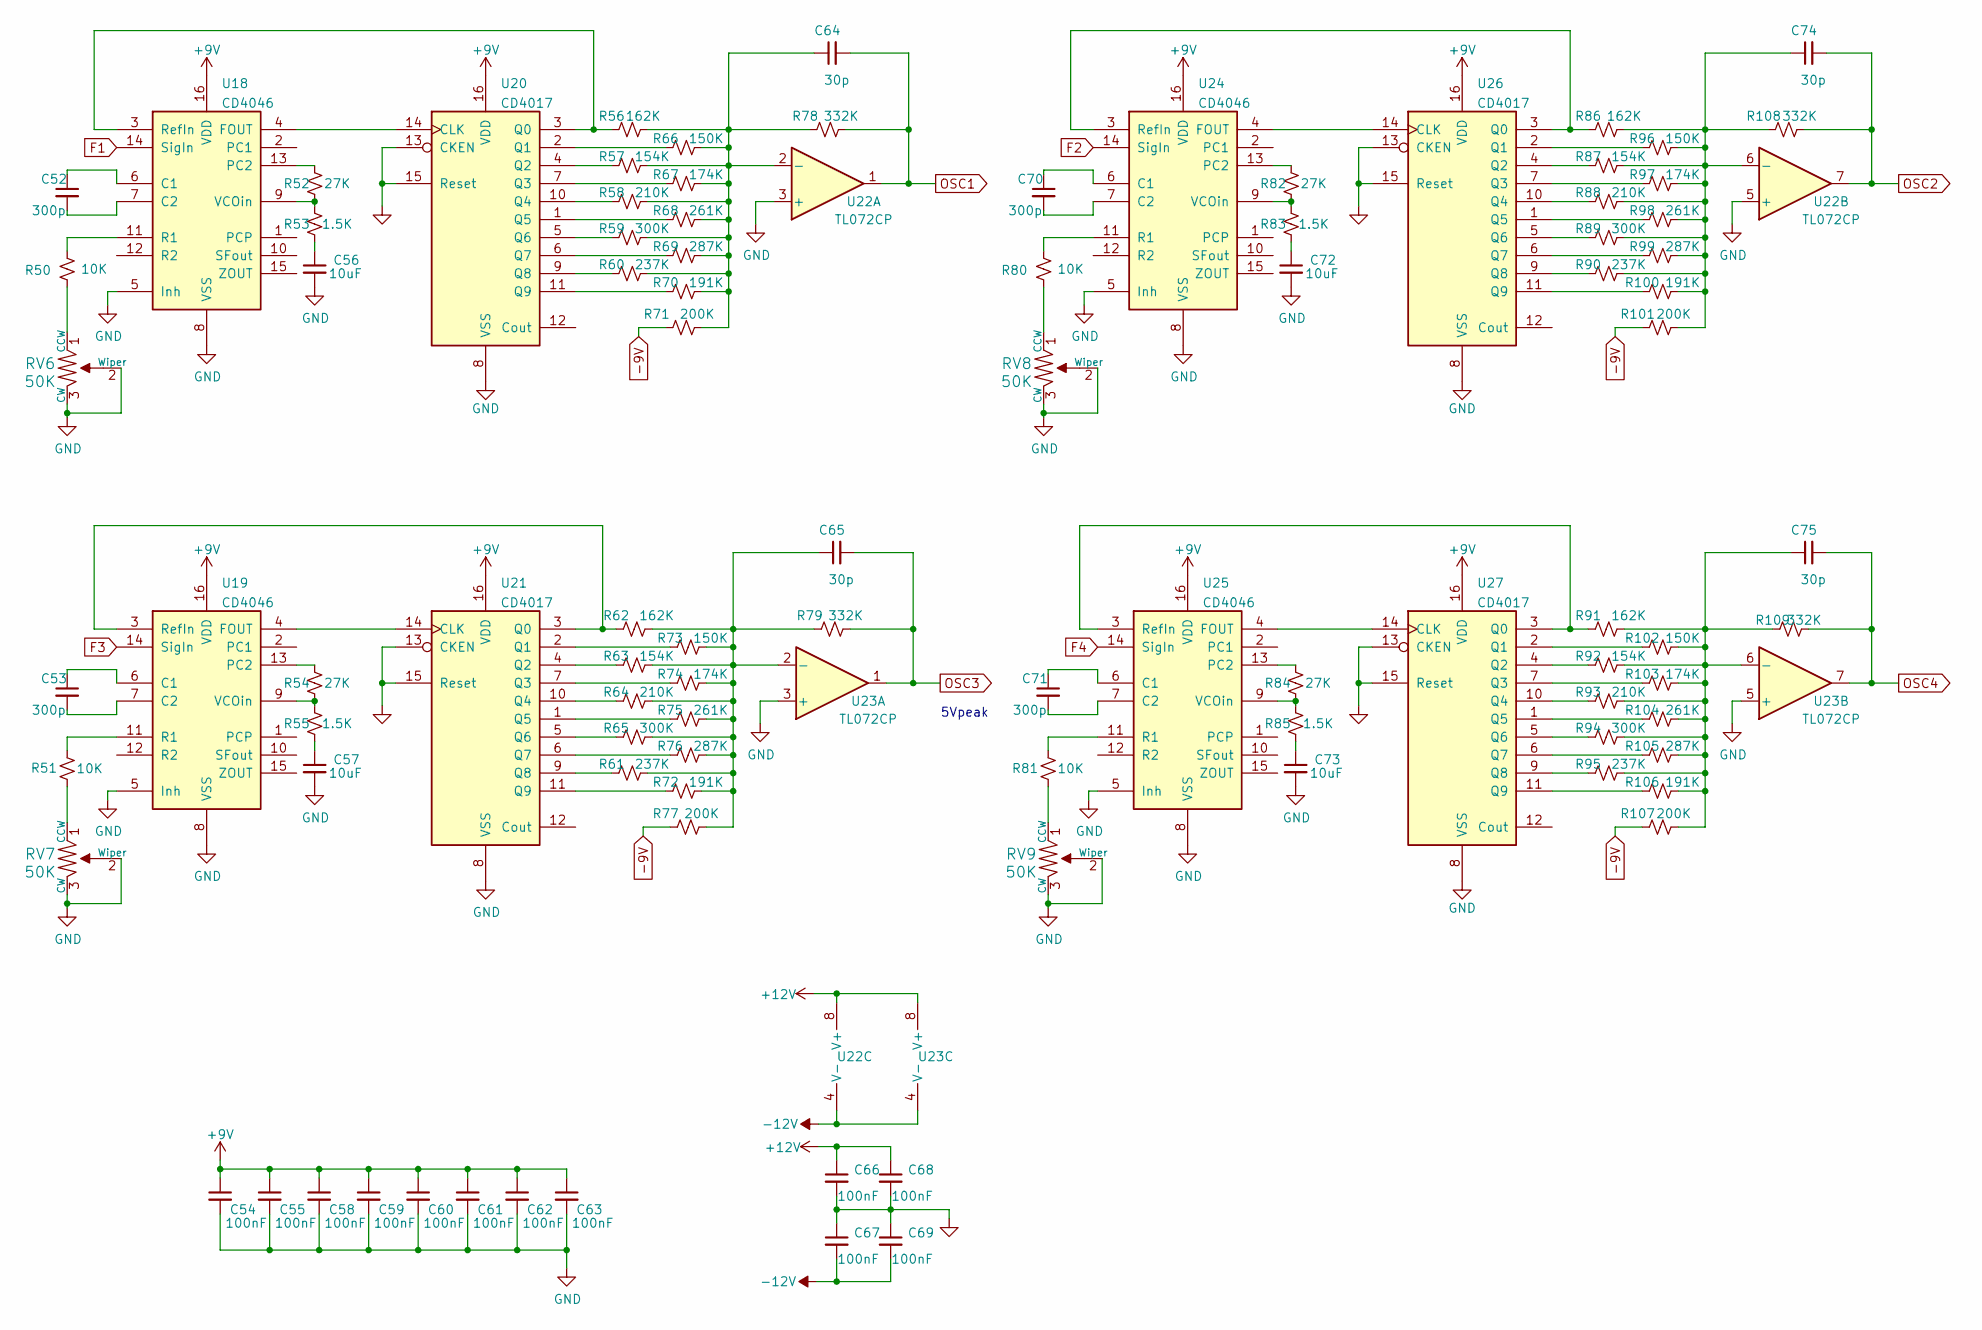
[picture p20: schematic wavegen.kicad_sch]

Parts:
C52, C53, C70, C71: 300p; C_0603_1608Metric_Pad1.08x0.95mm_HandSolder; Digi-Key Part BC2662CT-ND
C54, C55, C58, C59, C60, C61, C62, C63, C66, C67, C68, C69: 100nF; C_0805_2012Metric_Pad1.18x1.45mm_HandSolder; Digi-Key Part 478-10836-1-ND
C56, C57, C72, C73: 10uF; C_0805_2012Metric_Pad1.18x1.45mm_HandSolder; Digi-Key Part 478-10836-1-ND
C64, C65, C74, C75: 30p; C_0603_1608Metric_Pad1.08x0.95mm_HandSolder; Digi-Key Part BC2662CT-ND
R50, R51, R80, R81: 10K; R_0603_1608Metric; Digi-Key Part CF14JT10K0CT-ND
R52, R54, R82, R84: 27K; R_0805_2012Metric_Pad1.20x1.40mm_HandSolder; Digi-Key Part CF14JT10K0CT-ND
R53, R55, R83, R85: 1.5K; R_0805_2012Metric_Pad1.20x1.40mm_HandSolder; Digi-Key Part CF14JT10K0CT-ND
R56, R62, R86, R91: 162K; R_0603_1608Metric; Digi-Key Part CF14JT10K0CT-ND
R57, R63, R87, R92: 154K; R_0603_1608Metric; Digi-Key Part CF14JT10K0CT-ND
R58, R64, R88, R93: 210K; R_0603_1608Metric; Digi-Key Part CF14JT10K0CT-ND
R59, R65, R89, R94: 300K; R_0603_1608Metric; Digi-Key Part CF14JT10K0CT-ND
R60, R61, R90, R95: 237K; R_0603_1608Metric; Digi-Key Part CF14JT10K0CT-ND
R66, R73, R96, R102: 150K; R_0603_1608Metric; Digi-Key Part CF14JT10K0CT-ND
R67, R74, R97, R103: 174K; R_0603_1608Metric; Digi-Key Part CF14JT10K0CT-ND
R68, R75, R98, R104: 261K; R_0603_1608Metric; Digi-Key Part CF14JT10K0CT-ND
R69, R76, R99, R105: 287K; R_0603_1608Metric; Digi-Key Part CF14JT10K0CT-ND
R70, R72, R100, R106: 191K; R_0603_1608Metric; Digi-Key Part CF14JT10K0CT-ND
R71, R77, R101, R107: 200K; R_0603_1608Metric; Digi-Key Part CF14JT10K0CT-ND
R78, R79, R108, R109: 332K; R_0603_1608Metric; Digi-Key Part CF14JT10K0CT-ND
RV6, RV7, RV8, RV9: 50K; Potentiometer_Bourns_3224W_Vertical; Digi-Key Part 490-2881-ND
U18, U19, U24, U25: CD4046; TSSOP-16_4.4x5mm_P0.65mm; LCSC Part # C2651240
U20, U21, U26, U27: CD4017; SOIC-16_3.9x9.9mm_P1.27mm; Digi-Key Part 296-12808-1-ND
U22, U23: TL072CP; SOIC-8_3.9x4.9mm_P1.27mm; Digi-Key Part 296-1775-5-ND

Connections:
+9V: C54.1, C55.1, C58.1, C59.1, C60.1, C61.1, C62.1, C63.1, U18.16 (VDD), U19.16 (VDD), U20.16 (VDD), U21.16 (VDD), U24.16 (VDD), U25.16 (VDD), U26.16 (VDD), U27.16 (VDD); also elsewhere on the board
+12V: C66.1, C68.1, U22.8 (V+), U23.8 (V+); also elsewhere on the board
-9V: R71.1, R77.1, R101.1, R107.1; also elsewhere on the board
-12V: C67.2, C69.2, U22.4 (V-), U23.4 (V-); also elsewhere on the board
F1: U18.14 (SigIn); also elsewhere on the board
F2: U24.14 (SigIn); also elsewhere on the board
F3: U19.14 (SigIn); also elsewhere on the board
F4: U25.14 (SigIn); also elsewhere on the board
GND: C54.2, C55.2, C56.2, C57.2, C58.2, C59.2, C60.2, C61.2, C62.2, C63.2, C66.2, C67.1, C68.2, C69.1, C72.2, C73.2, RV6.2 (Wiper), RV6.3 (CW), RV7.2 (Wiper), RV7.3 (CW), RV8.2 (Wiper), RV8.3 (CW), RV9.2 (Wiper), RV9.3 (CW), U18.5 (Inh), U18.8 (VSS), U19.5 (Inh), U19.8 (VSS), U20.8 (VSS), U20.13 (CKEN), U20.15 (Reset), U21.8 (VSS), U21.13 (CKEN), U21.15 (Reset), U22.3 (+), U22.5 (+), U23.3 (+), U23.5 (+), U24.5 (Inh), U24.8 (VSS), U25.5 (Inh), U25.8 (VSS), U26.8 (VSS), U26.13 (CKEN), U26.15 (Reset), U27.8 (VSS), U27.13 (CKEN), U27.15 (Reset); also elsewhere on the board
unnamed: C52.1, U18.6 (C1)
unnamed: C52.2, U18.7 (C2)
unnamed: C53.1, U19.6 (C1)
unnamed: C53.2, U19.7 (C2)
unnamed: C56.1, R53.2
unnamed: C57.1, R55.2
unnamed: C64.1, R56.2, R57.2, R58.2, R59.2, R60.2, R66.2, R67.2, R68.2, R69.2, R70.2, R71.2, R78.1, U22.2 (-)
unnamed: C65.1, R61.2, R62.2, R63.2, R64.2, R65.2, R72.2, R73.2, R74.2, R75.2, R76.2, R77.2, R79.1, U23.2 (-)
unnamed: C70.1, U24.6 (C1)
unnamed: C70.2, U24.7 (C2)
unnamed: C71.1, U25.6 (C1)
unnamed: C71.2, U25.7 (C2)
unnamed: C72.1, R83.2
unnamed: C73.1, R85.2
unnamed: C74.1, R86.2, R87.2, R88.2, R89.2, R90.2, R96.2, R97.2, R98.2, R99.2, R100.2, R101.2, R108.1, U22.6 (-)
unnamed: C75.1, R91.2, R92.2, R93.2, R94.2, R95.2, R102.2, R103.2, R104.2, R105.2, R106.2, R107.2, R109.1, U23.6 (-)
unnamed: R50.1, U18.11 (R1)
unnamed: R50.2, RV6.1 (CCW)
unnamed: R51.1, U19.11 (R1)
unnamed: R51.2, RV7.1 (CCW)
unnamed: R52.1, U18.13 (PC2)
unnamed: R52.2, R53.1, U18.9 (VCOin)
unnamed: R54.1, U19.13 (PC2)
unnamed: R54.2, R55.1, U19.9 (VCOin)
unnamed: R56.1, U18.3 (RefIn), U20.3 (Q0)
unnamed: R57.1, U20.4 (Q2)
unnamed: R58.1, U20.10 (Q4)
unnamed: R59.1, U20.5 (Q6)
unnamed: R60.1, U20.9 (Q8)
unnamed: R61.1, U21.9 (Q8)
unnamed: R62.1, U19.3 (RefIn), U21.3 (Q0)
unnamed: R63.1, U21.4 (Q2)
unnamed: R64.1, U21.10 (Q4)
unnamed: R65.1, U21.5 (Q6)
unnamed: R66.1, U20.2 (Q1)
unnamed: R67.1, U20.7 (Q3)
unnamed: R68.1, U20.1 (Q5)
unnamed: R69.1, U20.6 (Q7)
unnamed: R70.1, U20.11 (Q9)
unnamed: R72.1, U21.11 (Q9)
unnamed: R73.1, U21.2 (Q1)
unnamed: R74.1, U21.7 (Q3)
unnamed: R75.1, U21.1 (Q5)
unnamed: R76.1, U21.6 (Q7)
unnamed: R80.1, U24.11 (R1)
unnamed: R80.2, RV8.1 (CCW)
unnamed: R81.1, U25.11 (R1)
unnamed: R81.2, RV9.1 (CCW)
unnamed: R82.1, U24.13 (PC2)
unnamed: R82.2, R83.1, U24.9 (VCOin)
unnamed: R84.1, U25.13 (PC2)
unnamed: R84.2, R85.1, U25.9 (VCOin)
unnamed: R86.1, U24.3 (RefIn), U26.3 (Q0)
unnamed: R87.1, U26.4 (Q2)
unnamed: R88.1, U26.10 (Q4)
unnamed: R89.1, U26.5 (Q6)
unnamed: R90.1, U26.9 (Q8)
unnamed: R91.1, U25.3 (RefIn), U27.3 (Q0)
unnamed: R92.1, U27.4 (Q2)
unnamed: R93.1, U27.10 (Q4)
unnamed: R94.1, U27.5 (Q6)
unnamed: R95.1, U27.9 (Q8)
unnamed: R96.1, U26.2 (Q1)
unnamed: R97.1, U26.7 (Q3)
unnamed: R98.1, U26.1 (Q5)
unnamed: R99.1, U26.6 (Q7)
unnamed: R100.1, U26.11 (Q9)
unnamed: R102.1, U27.2 (Q1)
unnamed: R103.1, U27.7 (Q3)
unnamed: R104.1, U27.1 (Q5)
unnamed: R105.1, U27.6 (Q7)
unnamed: R106.1, U27.11 (Q9)
unnamed: U18.4 (FOUT), U20.14 (CLK)
unnamed: U19.4 (FOUT), U21.14 (CLK)
unnamed: U24.4 (FOUT), U26.14 (CLK)
unnamed: U25.4 (FOUT), U27.14 (CLK)
OSC1: C64.2, R78.2, U22.1; also elsewhere on the board
OSC2: C74.2, R108.2, U22.7; also elsewhere on the board
OSC3: C65.2, R79.2, U23.1; also elsewhere on the board
OSC4: C75.2, R109.2, U23.7; also elsewhere on the board

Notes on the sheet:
5Vpeak

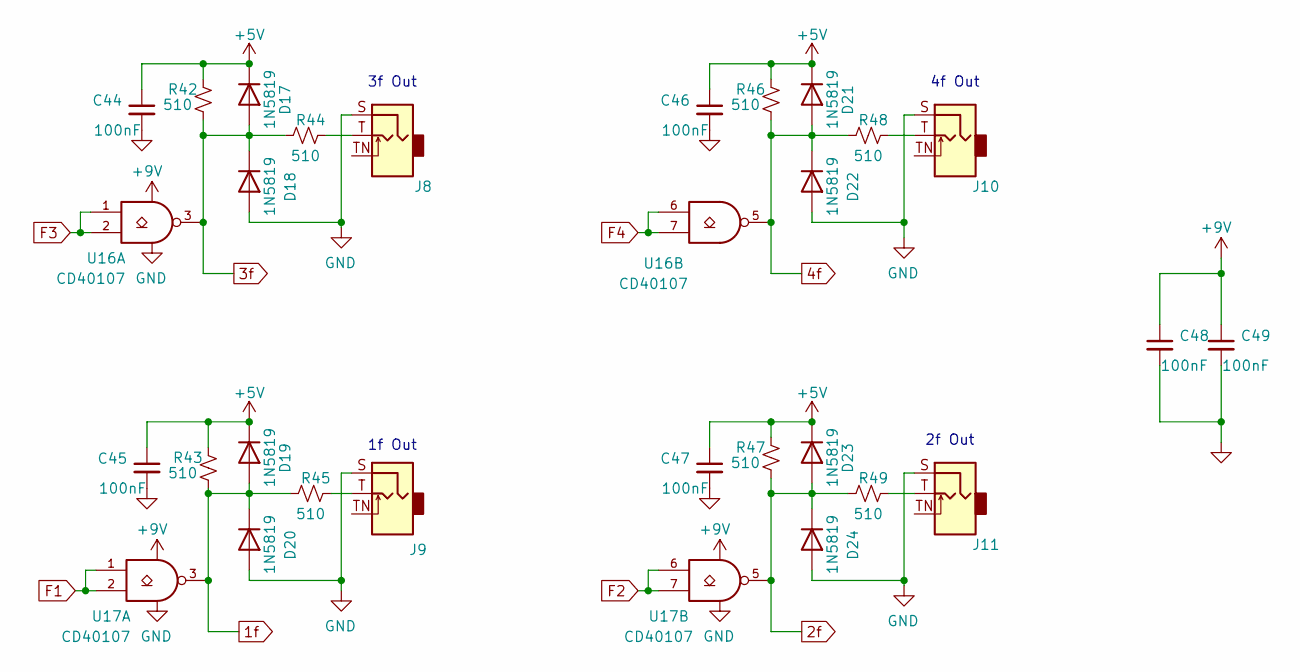
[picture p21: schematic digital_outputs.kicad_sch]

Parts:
C44, C45, C46, C47, C48, C49: 100nF; C_0805_2012Metric_Pad1.18x1.45mm_HandSolder; Digi-Key Part 478-10836-1-ND
D17, D18, D19, D20, D21, D22, D23, D24: 1N5819; D_SOD-323_HandSoldering; Digi-Key Part 478-7800-1-ND
J8, J9, J10, J11: 3.5mm Jack; Jack_3.5mm_QingPu_WQP-PJ398SM_Vertical; Digi-Key Part WM17366-ND
R42, R43, R46, R47: 510; R_0805_2012Metric_Pad1.20x1.40mm_HandSolder; Digi-Key Part PPC470W-1CT-ND
R44, R45, R48, R49: 510; R_0805_2012Metric_Pad1.20x1.40mm_HandSolder; Digi-Key Part CRT0805-FZ-1002ELFCT-ND
U16, U17: CD40107; SOIC-8_3.9x4.9mm_P1.27mm; LCSC Part # C2691402

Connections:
1f: D19.2 (A), D20.1 (K), R43.1, R45.2, U17.3
2f: D23.2 (A), D24.1 (K), R47.1, R49.2, U17.5
3f: D17.2 (A), D18.1 (K), R42.1, R44.2, U16.3
4f: D21.2 (A), D22.1 (K), R46.1, R48.2, U16.5
+5V: C44.1, C45.1, C46.1, C47.1, D17.1 (K), D19.1 (K), D21.1 (K), D23.1 (K), R42.2, R43.2, R46.2, R47.2; also elsewhere on the board
+9V: C48.1, C49.1, U16.8 (VCC), U17.8 (VCC); also elsewhere on the board
F1: U17.1, U17.2; also elsewhere on the board
F2: U17.6, U17.7; also elsewhere on the board
F3: U16.1, U16.2; also elsewhere on the board
F4: U16.6, U16.7; also elsewhere on the board
GND: C44.2, C45.2, C46.2, C47.2, C48.2, C49.2, D18.2 (A), D20.2 (A), D22.2 (A), D24.2 (A), J8.S, J9.S, J10.S, J11.S, U16.4 (GND), U17.4 (GND); also elsewhere on the board
unnamed: J8.T, R44.1
unnamed: J9.T, R45.1
unnamed: J10.T, R48.1
unnamed: J11.T, R49.1

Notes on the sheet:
2f Out
4f Out
3f Out
1f Out

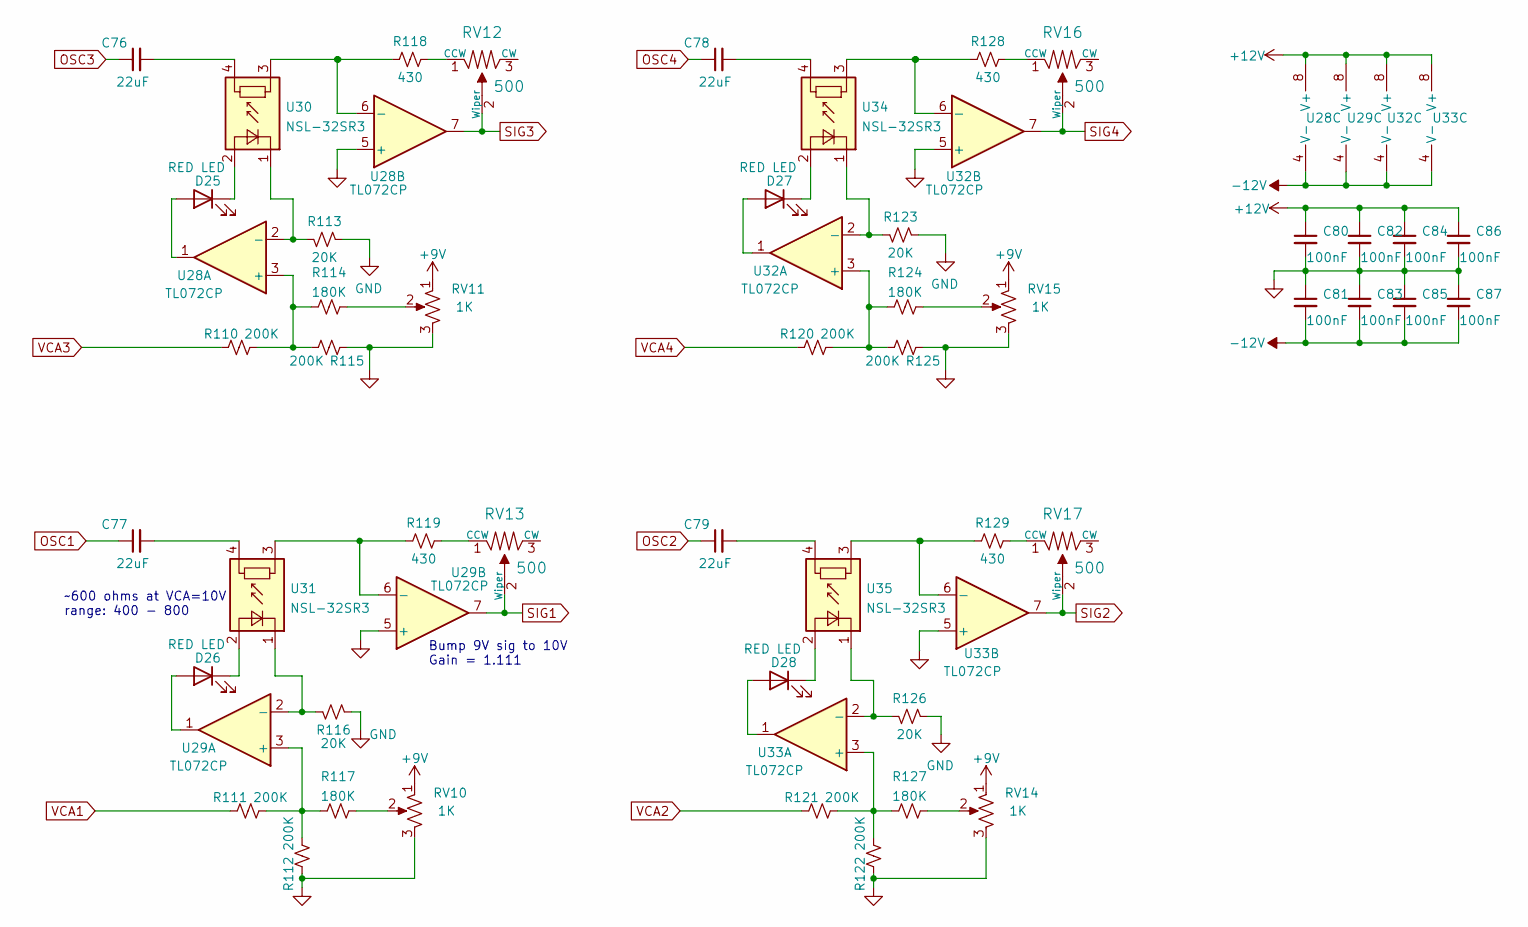
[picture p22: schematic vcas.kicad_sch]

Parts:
C76, C77, C78, C79: 22uF; C_0805_2012Metric_Pad1.18x1.45mm_HandSolder; Digi-Key Part 478-10836-1-ND
C80, C81, C82, C83, C84, C85, C86, C87: 100nF; C_0805_2012Metric_Pad1.18x1.45mm_HandSolder; Digi-Key Part 478-10836-1-ND
D25, D26, D27, D28: RED LED; LED_D3.0mm; Digi-Key Part 732-5005-ND
R110, R111, R112, R115, R120, R121, R122, R125: 200K; R_0603_1608Metric; Digi-Key Part CF14JT10K0CT-ND
R113, R116, R123, R126: 20K; R_0603_1608Metric; Digi-Key Part CRT0805-FZ-1002ELFCT-ND
R114, R117, R124, R127: 180K; R_0603_1608Metric; LCSC Part # C3016400
R118, R119, R128, R129: 430; R_0603_1608Metric; Digi-Key Part CRT0805-FZ-1002ELFCT-ND
RV10, RV11, RV14, RV15: 1K; Potentiometer_Bourns_PTV09A-1_Single_Vertical; Digi-Key Part PTV09A-4225F-B102-ND
RV12, RV13, RV16, RV17: 500; Potentiometer_Bourns_3224W_Vertical; LCSC Part # C116324
U28: TL072CP; SOIC-8_3.9x4.9mm_P1.27mm; LCSC Part # C6961
U29, U32, U33: TL072CP; SOIC-8_3.9x4.9mm_P1.27mm; Digi-Key Part 296-1775-5-ND
U30, U31, U34, U35: NSL-32SR3; Digi-Key Part NSL-32SR3-ND

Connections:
+9V: RV10.1, RV11.1, RV14.1, RV15.1; also elsewhere on the board
+12V: C80.1, C82.1, C84.1, C86.1, U28.8 (V+), U29.8 (V+), U32.8 (V+), U33.8 (V+); also elsewhere on the board
-12V: C81.2, C83.2, C85.2, C87.2, U28.4 (V-), U29.4 (V-), U32.4 (V-), U33.4 (V-); also elsewhere on the board
GND: C80.2, C81.1, C82.2, C83.1, C84.2, C85.1, C86.2, C87.1, R112.1, R113.2, R115.1, R116.2, R122.1, R123.2, R125.1, R126.2, RV10.3, RV11.3, RV14.3, RV15.3, U28.5 (+), U29.5 (+), U32.5 (+), U33.5 (+); also elsewhere on the board
unnamed: C76.2, U30.4
unnamed: C77.2, U31.4
unnamed: C78.2, U34.4
unnamed: C79.2, U35.4
unnamed: D25.1 (K), U30.2 (+)
unnamed: D25.2 (A), U28.1
unnamed: D26.1 (K), U31.2 (+)
unnamed: D26.2 (A), U29.1
unnamed: D27.1 (K), U34.2 (+)
unnamed: D27.2 (A), U32.1
unnamed: D28.1 (K), U35.2 (+)
unnamed: D28.2 (A), U33.1
unnamed: R110.2, R114.1, R115.2, U28.3 (+)
unnamed: R111.2, R112.2, R117.1, U29.3 (+)
unnamed: R113.1, U28.2 (-), U30.1 (-)
unnamed: R114.2, RV11.2
unnamed: R116.1, U29.2 (-), U31.1 (-)
unnamed: R117.2, RV10.2
unnamed: R118.1, RV12.1 (CCW)
unnamed: R118.2, U28.6 (-), U30.3
unnamed: R119.1, RV13.1 (CCW)
unnamed: R119.2, U29.6 (-), U31.3
unnamed: R120.2, R124.1, R125.2, U32.3 (+)
unnamed: R121.2, R122.2, R127.1, U33.3 (+)
unnamed: R123.1, U32.2 (-), U34.1 (-)
unnamed: R124.2, RV15.2
unnamed: R126.1, U33.2 (-), U35.1 (-)
unnamed: R127.2, RV14.2
unnamed: R128.1, RV16.1 (CCW)
unnamed: R128.2, U32.6 (-), U34.3
unnamed: R129.1, RV17.1 (CCW)
unnamed: R129.2, U33.6 (-), U35.3
OSC1: C77.1; also elsewhere on the board
OSC2: C79.1; also elsewhere on the board
OSC3: C76.1; also elsewhere on the board
OSC4: C78.1; also elsewhere on the board
SIG1: RV13.2 (Wiper), U29.7; also elsewhere on the board
SIG2: RV17.2 (Wiper), U33.7; also elsewhere on the board
SIG3: RV12.2 (Wiper), U28.7; also elsewhere on the board
SIG4: RV16.2 (Wiper), U32.7; also elsewhere on the board
VCA1: R111.1; also elsewhere on the board
VCA2: R121.1; also elsewhere on the board
VCA3: R110.1; also elsewhere on the board
VCA4: R120.1; also elsewhere on the board

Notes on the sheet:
Bump 9V sig to 10V Gain = 1.111
~600 ohms at VCA=10V range: 400 - 800

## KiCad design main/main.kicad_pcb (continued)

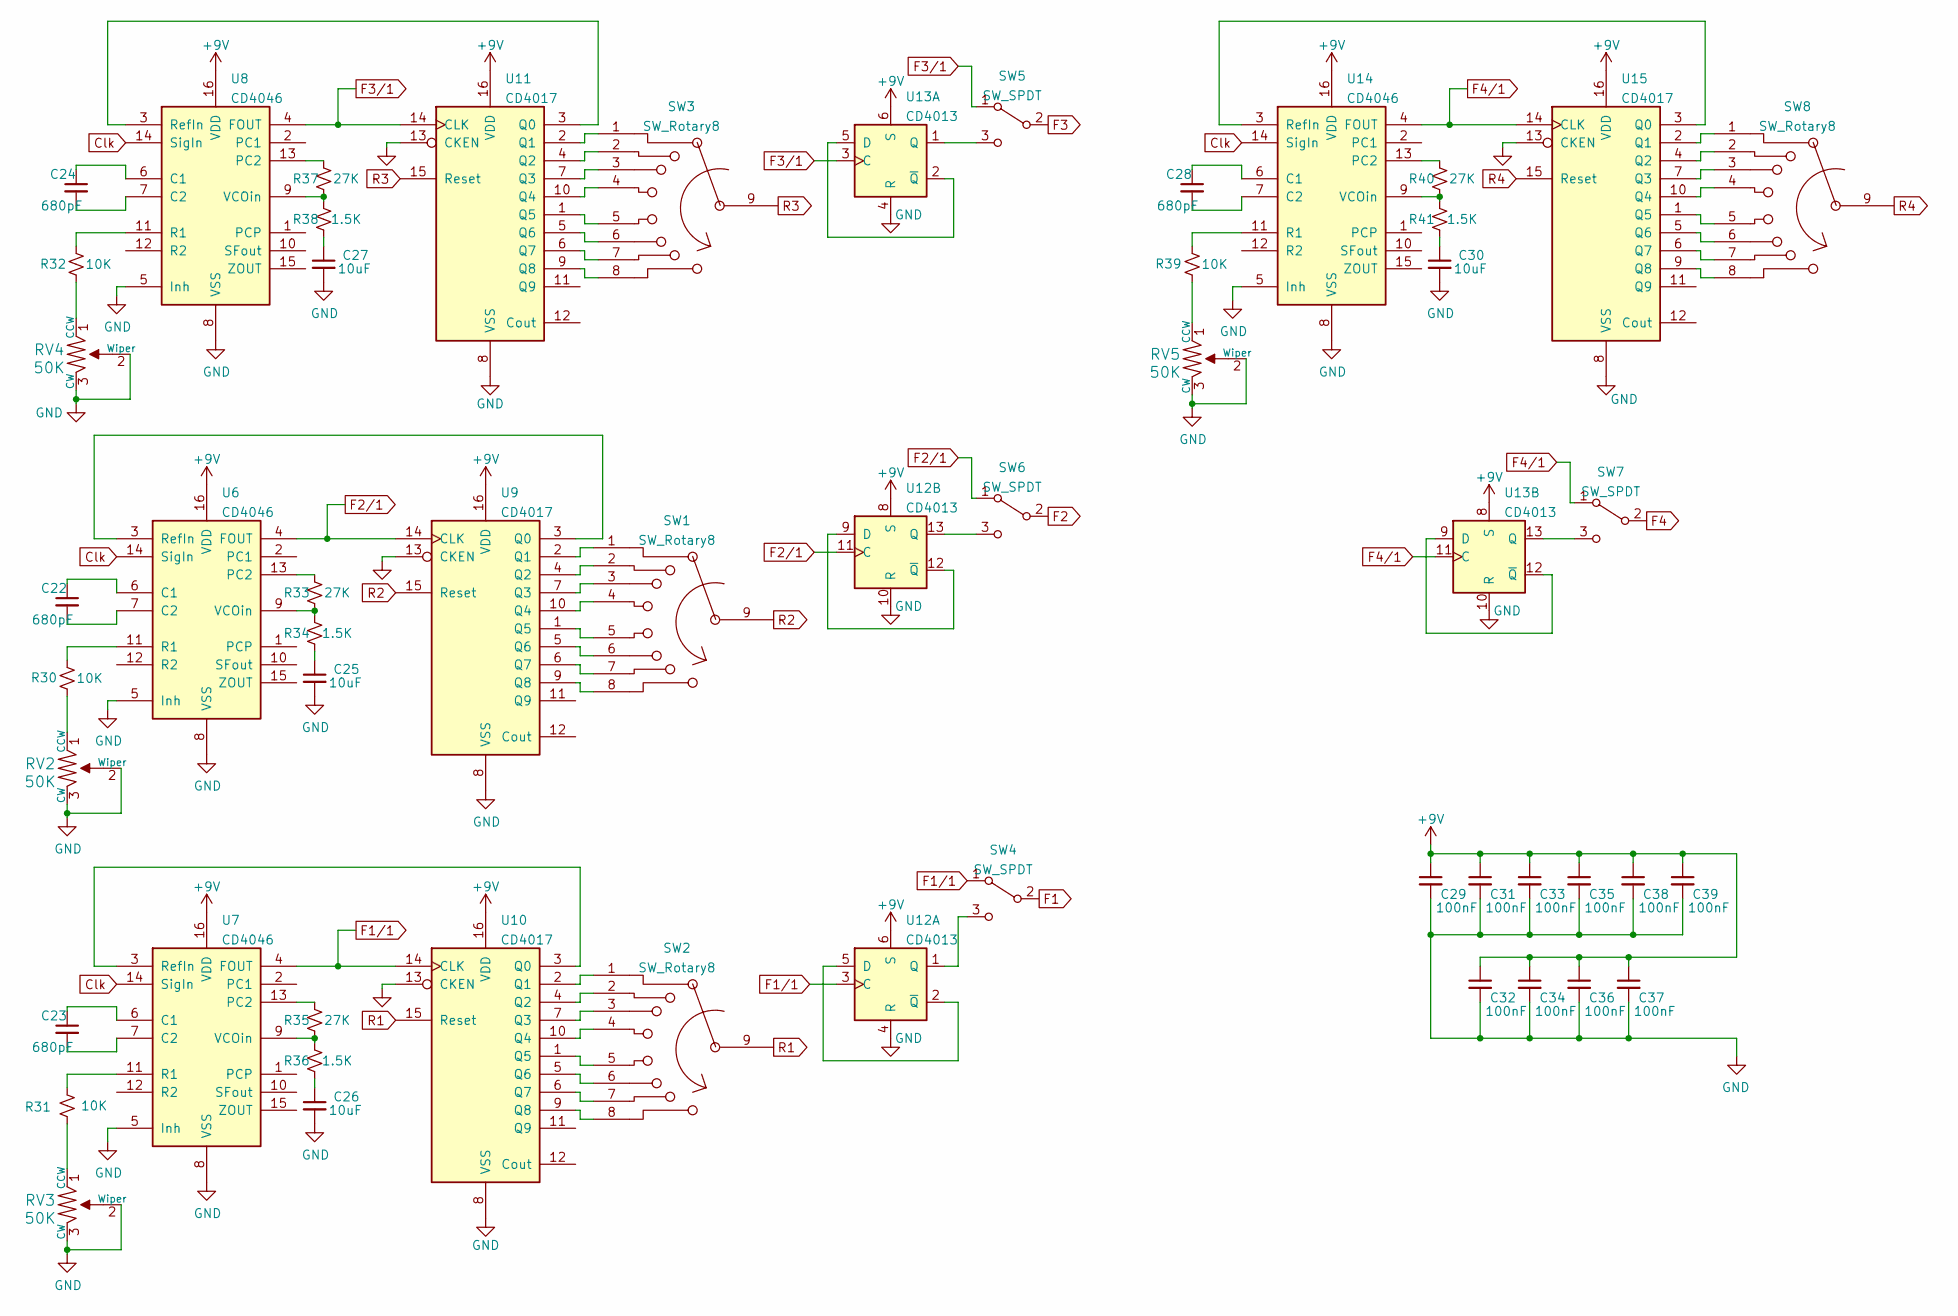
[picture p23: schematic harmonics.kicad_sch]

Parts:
C22, C23, C24, C28: 680pF; C_0805_2012Metric_Pad1.18x1.45mm_HandSolder; Digi-Key Part BC2662CT-ND
C25, C26, C27, C30: 10uF; C_0805_2012Metric_Pad1.18x1.45mm_HandSolder; Digi-Key Part 478-10836-1-ND
C29, C31, C32, C33, C34, C35, C36, C37, C38, C39: 100nF; C_0805_2012Metric_Pad1.18x1.45mm_HandSolder; Digi-Key Part 478-10836-1-ND
R30, R31, R32, R39: 10K; R_0603_1608Metric; Digi-Key Part CF14JT10K0CT-ND
R33, R35, R37, R40: 27K; R_0805_2012Metric_Pad1.20x1.40mm_HandSolder; Digi-Key Part CF14JT10K0CT-ND
R34, R36, R38, R41: 1.5K; R_0805_2012Metric_Pad1.20x1.40mm_HandSolder; Digi-Key Part CF14JT10K0CT-ND
RV2, RV3, RV4, RV5: 50K; Potentiometer_Bourns_3224W_Vertical; Digi-Key Part 490-2881-ND
SW1, SW2, SW3, SW8: SW_Rotary8; CPA_8; Digi-Key Part 1528-2925-ND
SW4, SW5, SW6, SW7: SW_SPDT; Toggle_Switch_100SP1T1B4M2QE; Digi-Key Part 2449-ANT11SF1CQE-ND
U6, U7, U8, U14: CD4046; TSSOP-16_4.4x5mm_P0.65mm; LCSC Part # C2651240
U9, U10, U11, U15: CD4017; SOIC-16_3.9x9.9mm_P1.27mm; Digi-Key Part 296-12808-1-ND
U12, U13: CD4013; SOIC-14_3.9x8.7mm_P1.27mm; LCSC Part # C13527

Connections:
+9V: C29.1, C31.1, C32.1, C33.1, C34.1, C35.1, C36.1, C37.1, C38.1, C39.1, U6.16 (VDD), U7.16 (VDD), U8.16 (VDD), U9.16 (VDD), U10.16 (VDD), U11.16 (VDD), U12.6 (S), U12.8 (S), U13.6 (S), U13.8 (S), U14.16 (VDD), U15.16 (VDD); also elsewhere on the board
Clk: U6.14 (SigIn), U7.14 (SigIn), U8.14 (SigIn), U14.14 (SigIn); also elsewhere on the board
F1: SW4.2 (B); also elsewhere on the board
F1/1: SW4.1 (A), U7.4 (FOUT), U10.14 (CLK), U12.3 (C)
F2: SW6.2 (B); also elsewhere on the board
F2/1: SW6.1 (A), U6.4 (FOUT), U9.14 (CLK), U12.11 (C)
F3: SW5.2 (B); also elsewhere on the board
F3/1: SW5.1 (A), U8.4 (FOUT), U11.14 (CLK), U13.3 (C)
F4: SW7.2 (B); also elsewhere on the board
F4/1: SW7.1 (A), U13.11 (C), U14.4 (FOUT), U15.14 (CLK)
GND: C25.2, C26.2, C27.2, C29.2, C30.2, C31.2, C32.2, C33.2, C34.2, C35.2, C36.2, C37.2, C38.2, C39.2, RV2.2 (Wiper), RV2.3 (CW), RV3.2 (Wiper), RV3.3 (CW), RV4.2 (Wiper), RV4.3 (CW), RV5.2 (Wiper), RV5.3 (CW), U6.5 (Inh), U6.8 (VSS), U7.5 (Inh), U7.8 (VSS), U8.5 (Inh), U8.8 (VSS), U9.8 (VSS), U9.13 (CKEN), U10.8 (VSS), U10.13 (CKEN), U11.8 (VSS), U11.13 (CKEN), U12.4 (R), U12.10 (R), U13.4 (R), U13.10 (R), U14.5 (Inh), U14.8 (VSS), U15.8 (VSS), U15.13 (CKEN); also elsewhere on the board
unnamed: C22.1, U6.6 (C1)
unnamed: C22.2, U6.7 (C2)
unnamed: C23.1, U7.6 (C1)
unnamed: C23.2, U7.7 (C2)
unnamed: C24.1, U8.6 (C1)
unnamed: C24.2, U8.7 (C2)
unnamed: C25.1, R34.2
unnamed: C26.1, R36.2
unnamed: C27.1, R38.2
unnamed: C28.1, U14.6 (C1)
unnamed: C28.2, U14.7 (C2)
unnamed: C30.1, R41.2
unnamed: R30.1, U6.11 (R1)
unnamed: R30.2, RV2.1 (CCW)
unnamed: R31.1, U7.11 (R1)
unnamed: R31.2, RV3.1 (CCW)
unnamed: R32.1, U8.11 (R1)
unnamed: R32.2, RV4.1 (CCW)
unnamed: R33.1, U6.13 (PC2)
unnamed: R33.2, R34.1, U6.9 (VCOin)
unnamed: R35.1, U7.13 (PC2)
unnamed: R35.2, R36.1, U7.9 (VCOin)
unnamed: R37.1, U8.13 (PC2)
unnamed: R37.2, R38.1, U8.9 (VCOin)
unnamed: R39.1, U14.11 (R1)
unnamed: R39.2, RV5.1 (CCW)
unnamed: R40.1, U14.13 (PC2)
unnamed: R40.2, R41.1, U14.9 (VCOin)
unnamed: SW1.1, U9.2 (Q1)
unnamed: SW1.2, U9.4 (Q2)
unnamed: SW1.3, U9.7 (Q3)
unnamed: SW1.4, U9.10 (Q4)
unnamed: SW1.5, U9.1 (Q5)
unnamed: SW1.6, U9.5 (Q6)
unnamed: SW1.7, U9.6 (Q7)
unnamed: SW1.8, U9.9 (Q8)
unnamed: SW2.1, U10.2 (Q1)
unnamed: SW2.2, U10.4 (Q2)
unnamed: SW2.3, U10.7 (Q3)
unnamed: SW2.4, U10.10 (Q4)
unnamed: SW2.5, U10.1 (Q5)
unnamed: SW2.6, U10.5 (Q6)
unnamed: SW2.7, U10.6 (Q7)
unnamed: SW2.8, U10.9 (Q8)
unnamed: SW3.1, U11.2 (Q1)
unnamed: SW3.2, U11.4 (Q2)
unnamed: SW3.3, U11.7 (Q3)
unnamed: SW3.4, U11.10 (Q4)
unnamed: SW3.5, U11.1 (Q5)
unnamed: SW3.6, U11.5 (Q6)
unnamed: SW3.7, U11.6 (Q7)
unnamed: SW3.8, U11.9 (Q8)
unnamed: SW4.3 (C), U12.1 (Q)
unnamed: SW5.3 (C), U13.1 (Q)
unnamed: SW6.3 (C), U12.13 (Q)
unnamed: SW7.3 (C), U13.13 (Q)
unnamed: SW8.1, U15.2 (Q1)
unnamed: SW8.2, U15.4 (Q2)
unnamed: SW8.3, U15.7 (Q3)
unnamed: SW8.4, U15.10 (Q4)
unnamed: SW8.5, U15.1 (Q5)
unnamed: SW8.6, U15.5 (Q6)
unnamed: SW8.7, U15.6 (Q7)
unnamed: SW8.8, U15.9 (Q8)
unnamed: U6.3 (RefIn), U9.3 (Q0)
unnamed: U7.3 (RefIn), U10.3 (Q0)
unnamed: U8.3 (RefIn), U11.3 (Q0)
unnamed: U12.2 (~Q), U12.5 (D)
unnamed: U12.9 (D), U12.12 (~Q)
unnamed: U13.2 (~Q), U13.5 (D)
unnamed: U13.9 (D), U13.12 (~Q)
unnamed: U14.3 (RefIn), U15.3 (Q0)
R1: SW2.9, U10.15 (Reset)
R2: SW1.9, U9.15 (Reset)
R3: SW3.9, U11.15 (Reset)
R4: SW8.9, U15.15 (Reset)

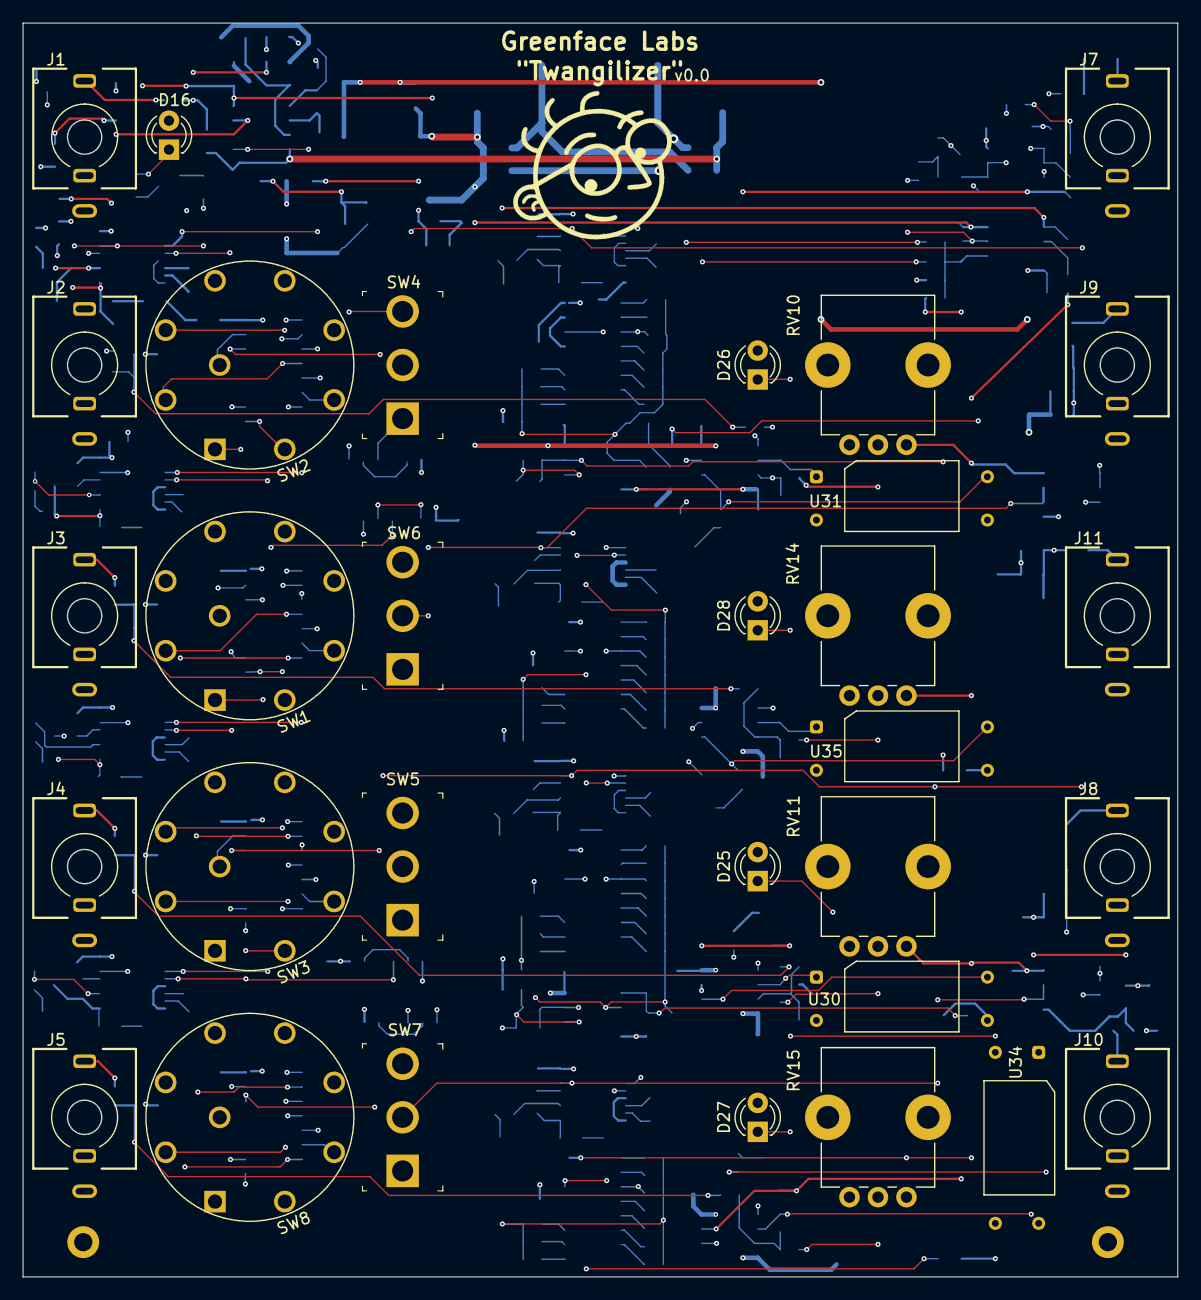
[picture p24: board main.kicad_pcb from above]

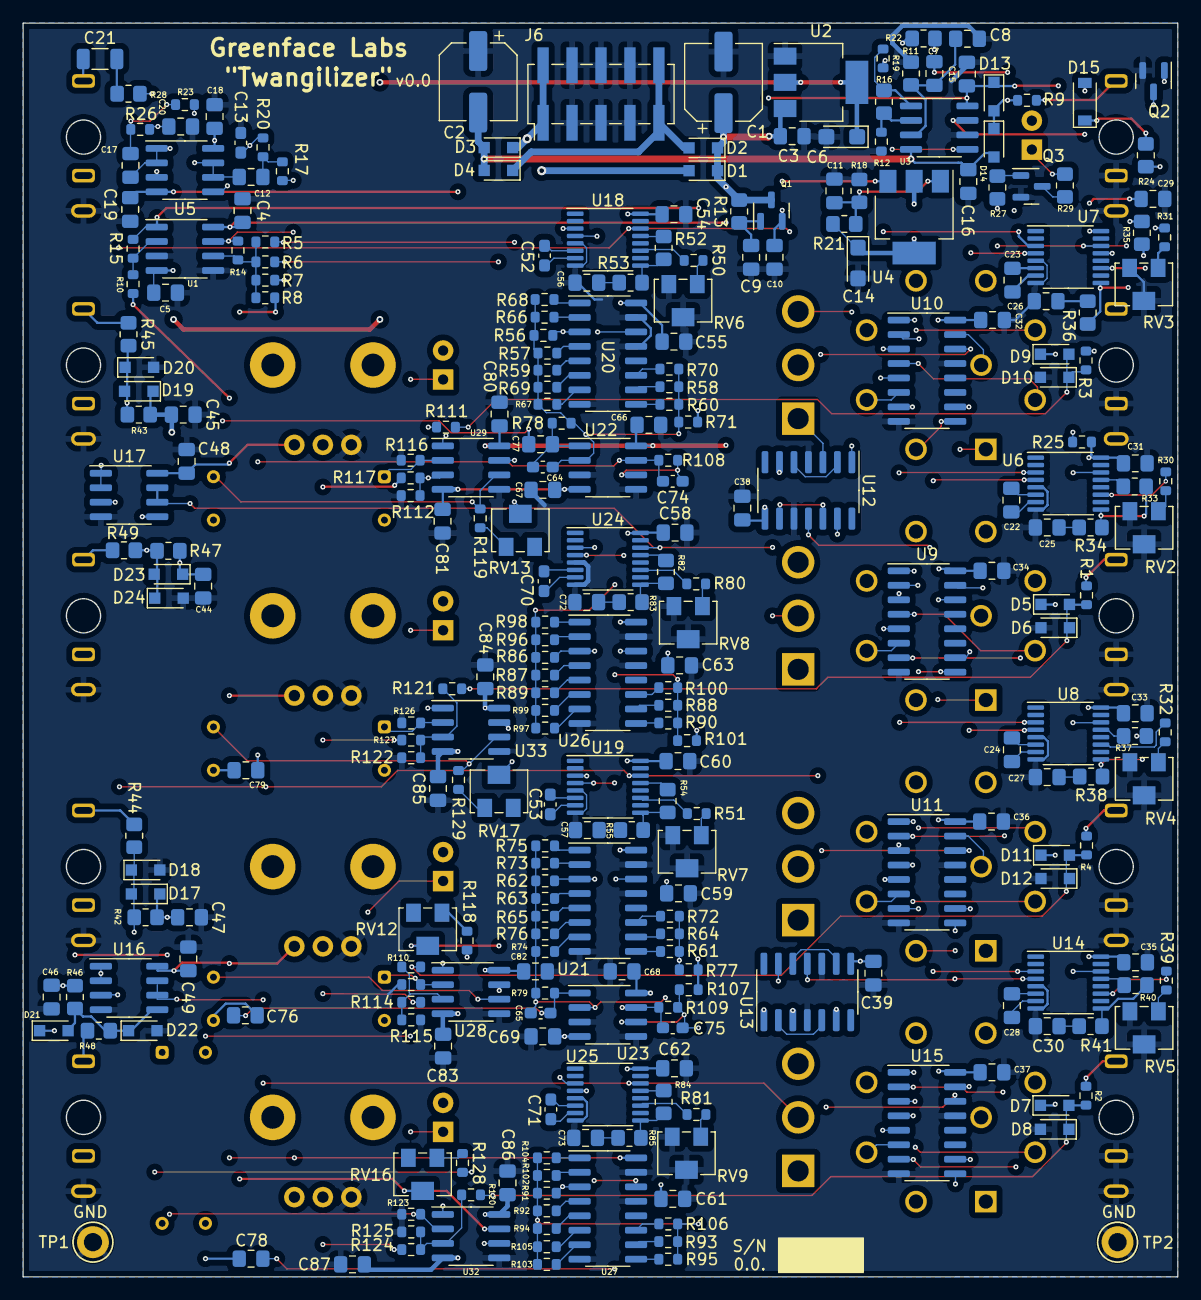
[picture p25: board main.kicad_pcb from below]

Board: 4 copper layers, 101.3 x 110.0 mm, 314 parts (282 on the bottom side), 251 nets.

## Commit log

2024-01-17 Init checkin
    [digital_outputs.kicad_sch, harmonics.kicad_sch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]
2024-01-18 Switched PLL cap to 680p
    [harmonics.kicad_sch, main.csv, main.kicad_pcb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]
2024-01-20 Switch to Thonk jacks.
    Reduces use of extended parts.
    [digital_outputs.kicad_sch, harmonics.kicad_sch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]
2024-02-06 Version 1.0
    [digital_outputs.kicad_sch, filters.kicad_sch, harmonics.kicad_sch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]
2024-02-06 The real v1.0
    [main-B_Cu.gbr, main-B_Mask.gbr, main-B_Paste.gbr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]
2024-02-21 v1.0
    Docs still need work.
    Oscillators.sch not used. Saved just in case.
    [VCO Pickoff Meas.xlsx, VCO Pickoff Plan.xlsx, filters.kicad_sch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]
2024-03-03 Work in progress
    Adds User Manual
    Changes CV range to 0 - 8V
    Adds spice vactrol test circuit.
    Adds VCA spice study
    Updates other spice and excel files.
    [VCO Pickoff Meas.xlsx, digital_outputs.kicad_sch, filters.kicad_sch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]
2024-03-14 Create CLK Pickoff.xlsx
    Resistor planner
    [CLK Pickoff.xlsx]
2024-03-14 Latest gain plan.
    Version 1.1
    Sent to JLCPCB
    [VCO Pickoff Meas.xlsx, VCO Pickoff Plan.xlsx, filters.kicad_sch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]
2024-04-28 Version 1.2
    [VCO Pickoff Meas.xlsx, VCO Pickoff Plan.xlsx, digital_outputs.kicad_sch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]
